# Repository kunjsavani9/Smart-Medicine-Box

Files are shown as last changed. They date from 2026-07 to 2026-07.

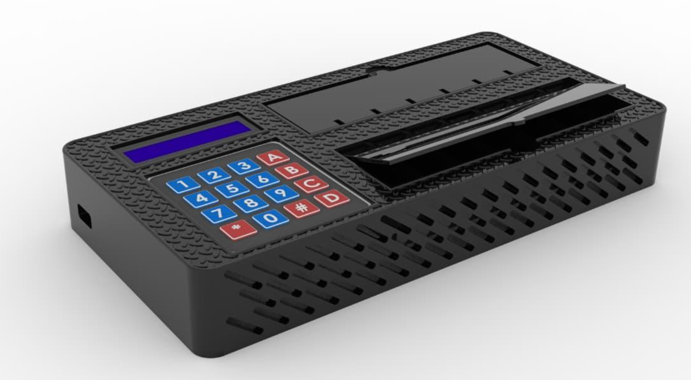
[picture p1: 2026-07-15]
images/Solidworks/Assembly.png

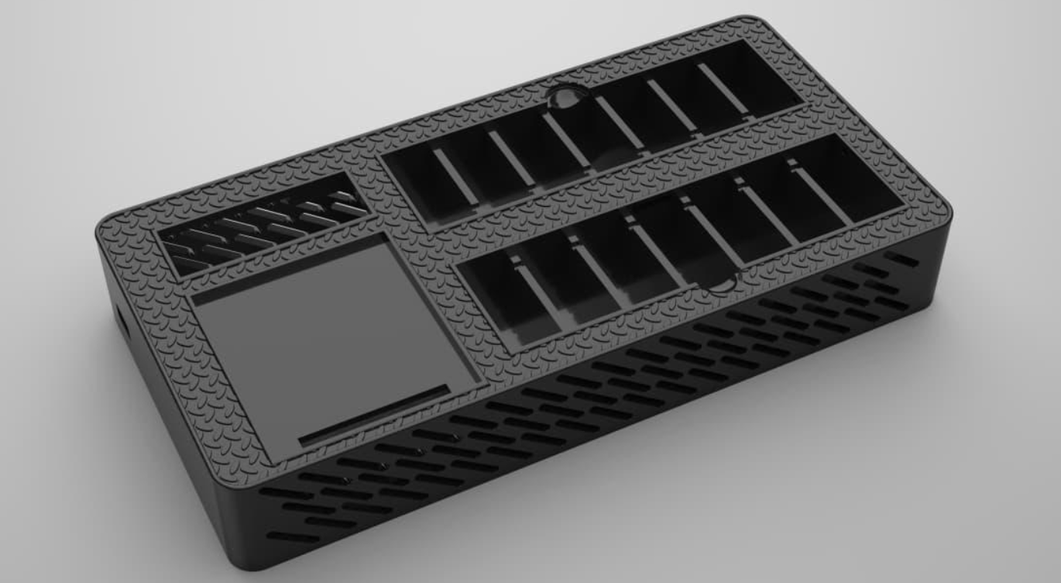
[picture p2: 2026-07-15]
images/Solidworks/Base.png

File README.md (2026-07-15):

# Smart Medicine Box 💊

An ESP32-based smart medicine box that reminds users to take their medication on time, verifies whether medicine has actually been removed from the compartment, and sends real-time alerts via Telegram. Built with a keypad interface, LCD display, force sensor, and cloud connectivity through Blynk.

---

## ✨ Features

- **Scheduled alarms** — set medication times through a 4x4 keypad; a buzzer sounds when it's time to take medicine.
- **Take-verification** — an FSR (force sensor) detects whether the medicine has actually been removed from the compartment before silencing the alarm.
- **Telegram notifications** — real-time messages sent to your phone when an alarm triggers or medicine is taken/missed.
- **Blynk IoT dashboard** — monitor and control the box remotely over WiFi.
- **LCD status display** — 16x2 LCD (I2C) shows the clock, alarms, and system messages.
- **Password protection** — secure access to settings with a changeable PIN.
- **NTP time sync** — keeps accurate time over WiFi.

---

## 🔧 Hardware

| Component | Purpose |
|---|---|
| ESP32 Dev Board | Main microcontroller (WiFi + processing) |
| 4x4 Membrane Keypad | User input (set alarms, enter password) |
| 16x2 LCD + I2C backpack | Display clock, alarms, messages |
| FSR 402 Force Sensor | Detect presence/removal of medicine |
| Passive Buzzer | Audible alarm |
| 10 kΩ Resistor | Pull-down for FSR analog reading |
| USB Power Bank *(or 18650 + TP4056 + MT3608)* | Power supply |

### Wiring notes

- **FSR** wired as: `3.3V → FSR leg 1`, `FSR leg 2 → GPIO34 + top of 10kΩ resistor`, `resistor bottom → GND`.
- **GPIO34 is input-only** on the ESP32 — used here for the analog FSR reading.
- FSR logic: reading of **0 = medicine absent** (buzzer activates); reading **≥ 2500 = medicine present** (buzzer stops).

See [`hardware/`](hardware/) for the full circuit diagram.

---

## 📁 Repository Structure

```
Smart-Medicine-Box/
├── firmware/          # ESP32 Arduino sketch (.ino) + config template
├── hardware/          # Circuit diagram and wiring notes
├── 3d-Models/         # Enclosure models — STL + SolidWorks source
│   ├── Base.STL / Base.SLDPRT
│   ├── Cap.STL  / Cap.SLDPRT
│   ├── Cover.STL / Cover.SLDPRT
│   └── Assem1.SLDASM        # Full assembly
├── docs/              # report, poster
├── images/            # Build and assembly photos, flow chart
├── LICENSE            # MIT
└── README.md
```

---

## 🚀 Getting Started

### 1. Prerequisites
- [Arduino IDE](https://www.arduino.cc/en/software) with the **ESP32 board package** installed
- Libraries: `WiFiClientSecure`, `Blynk`, `LiquidCrystal_I2C`, `Keypad`, and an NTP client

### 2. Configure your secrets
Copy the config template and fill in your own credentials:

```bash
cp firmware/config_example.h firmware/config.h
```

Edit `firmware/config.h`:

```cpp
#define WIFI_SSID       "your_wifi_name"
#define WIFI_PASSWORD   "your_wifi_password"
#define BLYNK_AUTH      "your_blynk_token"
#define TELEGRAM_TOKEN  "your_bot_token"
#define TELEGRAM_CHAT_ID "your_chat_id"
```

> ⚠️ **Never commit `config.h`** — it contains secrets and is git-ignored. Only `config_example.h` (with blanks) belongs in the repo.

### 3. Set up the Telegram bot
1. Message [@BotFather](https://t.me/BotFather) on Telegram and create a new bot to get your **token**.
2. Send your new bot a message, then get your **chat ID** (e.g. via [@userinfobot](https://t.me/userinfobot)).
3. Paste both into `config.h`.

### 4. Flash the board
Open `firmware/smart_medicine_box.ino` in the Arduino IDE, select your ESP32 board and port, and click **Upload**.

---

## 📖 Usage

- **Clock screen** is the default view (shows current time from NTP).
- **Set an alarm** using the keypad menu.
- When an alarm fires, the **buzzer sounds** and a **Telegram alert** is sent.
- Remove the medicine — the **FSR detects removal** and stops the buzzer.
- **Change password**: press `#` on the clock screen → `D` → enter old password → enter new password.

See [`docs/user_manual`](docs/) for the full keypad reference and LCD message guide.

---

## 🛠️ Troubleshooting

- **Telegram SSL `-5` error / `401 Unauthorized`** — usually an invalid bot token. Regenerate the token with BotFather and update `config.h`. The firmware uses `WiFiClientSecure` with `setInsecure()` to bypass certificate validation.
- **FSR reads erratically** — confirm the 10 kΩ pull-down resistor is wired correctly and you're using GPIO34.
- **LCD blank** — check the I2C address (commonly `0x27` or `0x3F`) and SDA/SCL wiring.

---

## 📄 License

Released under the [MIT License](LICENSE).

---

## 🙌 Acknowledgements

Built by Kunj as a hardware + software IoT project integrating ESP32, Telegram Bot API, and Blynk.

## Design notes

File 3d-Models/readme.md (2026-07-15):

# 3D Models — AUSHADH Enclosure

3D-printable models and editable CAD source for the AUSHADH Smart Medicine Box enclosure.

## Files

| File | Type | Description |
|---|---|---|
| `Base.STL` / `Base.SLDPRT` | Print + Source | Main body — houses the electronics, with the keypad cutout (top-left), LCD window (top-right), two buzzer holes (middle-left), and two columns of 7 pill compartments |
| `Cap.STL` / `Cap.SLDPRT` | Print + Source | Compartment lid / cap |
| `Cover.STL` / `Cover.SLDPRT` | Print + Source | Top cover |
| `Assem1.SLDASM` | Assembly | Full SolidWorks assembly of all parts |

- **`.STL`** files are ready to slice and print.
- **`.SLDPRT` / `.SLDASM`** are the editable SolidWorks source files.

## Printing

- **Material:** PLA or PETG
- **Layer height:** 0.2 mm
- **Infill:** 15–20%
- **Supports:** as needed for compartment overhangs and cutouts
- Print `Base`, `Cap`, and `Cover` separately, then assemble.

## Editing in SolidWorks

Open the `.SLDPRT` / `.SLDASM` files directly. When **importing an STL** into SolidWorks, set the units to **millimeters** (*Options → Import → Solid Body*) so dimensions come in correctly.

## Layout

The enclosure follows the project's hand-drawn layout:

- **Keypad** — top-left
- **LCD** — top-right
- **Buzzer** — two holes, middle-left
- **Pill compartments** — two columns of 7 (14 total), covering a full week of twice-daily doses

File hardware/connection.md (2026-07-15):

# AUSHADH — Smart Medicine Box: Wiring & Connections

Wiring reference for the ESP32-based smart medicine box. All logic runs at **3.3 V** — do **not** feed 5 V into any ESP32 GPIO.

> ⚠️ **Pin numbers below are the typical mapping.** Confirm they match the `#define` / pin declarations at the top of your Arduino sketch and adjust either the wiring or the code so they agree.

---

## Components

| # | Component | Interface |
|---|---|---|
| 1 | ESP32 Dev Board | Main controller (Wi-Fi + logic) |
| 2 | 4×4 Membrane Keypad | 8 digital I/O |
| 3 | 16×2 LCD + I2C backpack | I2C (SDA/SCL) |
| 4 | Passive Buzzer | 1 digital I/O |
| 5 | FSR 402 Force Sensor | 1 analog input + 10 kΩ resistor |
| 6 | Power source | USB / battery (see below) |

---

## 1. FSR 402 Force Sensor (pill detection)

Wired as a voltage divider. **GPIO34 is input-only** — correct for analog reading.

| FSR / Divider | Connects to |
|---|---|
| FSR leg 1 | **3.3 V** |
| FSR leg 2 | **GPIO34** *and* top of 10 kΩ resistor |
| 10 kΩ resistor (bottom) | **GND** |

```
3.3V ──[ FSR ]──┬── GPIO34  (analog in)
                │
             [ 10kΩ ]
                │
               GND
```

**Logic:** reading `0` = medicine absent → buzzer activates; reading `≥ 2500` = medicine present → buzzer stops.

---

## 2. 16×2 LCD (I2C backpack)

| LCD backpack | ESP32 |
|---|---|
| VCC | **5 V (VIN)** *(most I2C backpacks need 5 V; the SDA/SCL lines stay 3.3 V-safe)* |
| GND | GND |
| SDA | **GPIO21** |
| SCL | **GPIO22** |

> If your LCD stays blank, check the I2C address in code (commonly `0x27` or `0x3F`) and confirm SDA/SCL aren't swapped.

---

## 3. 4×4 Membrane Keypad

Eight ribbon pins — 4 rows + 4 columns. From pin 1 (leftmost) to pin 8:

| Keypad pin | Signal | ESP32 GPIO |
|---|---|---|
| 1 | Row 1 | **GPIO13** |
| 2 | Row 2 | **GPIO14** |
| 3 | Row 3 | **GPIO27** |
| 4 | Row 4 | **GPIO26** |
| 5 | Col 1 | **GPIO25** |
| 6 | Col 2 | **GPIO33** |
| 7 | Col 3 | **GPIO32** |
| 8 | Col 4 | **GPIO4** |

No external resistors needed — the `Keypad` library uses the ESP32's internal pull-ups.

---

## 4. Passive Buzzer

| Buzzer | ESP32 |
|---|---|
| + (signal) | **GPIO23** |
| − | GND |

> A passive buzzer needs a driven tone signal (e.g. `tone()` / PWM). If you have an **active** buzzer instead, a plain HIGH/LOW toggle is enough.

---

## 5. Power

**Option A — USB power bank (simplest):** plug into the ESP32's USB port. Onboard regulator supplies 3.3 V. Recommended for demos.

**Option B — Rechargeable battery pack:**

```
18650 cell ──> TP4056 (charge/protect) ──> MT3608 (boost to 5V) ──> ESP32 5V (VIN)
```

- **TP4056**: safe Li-ion charging + protection.
- **MT3608**: boost the ~3.7 V cell up to 5 V; set the output with its trim pot **before** connecting the ESP32.

---

## Common Ground

**All GNDs must be tied together** — ESP32, LCD, keypad, buzzer, FSR divider, and power source share one common ground. Missing common ground is the most frequent cause of erratic readings.

---

## Quick Pin Summary

| ESP32 Pin | Used by |
|---|---|
| GPIO34 | FSR analog in (input-only) |
| GPIO21 / GPIO22 | LCD I2C SDA / SCL |
| GPIO13, 14, 27, 26 | Keypad rows 1–4 |
| GPIO25, 33, 32, 4 | Keypad cols 1–4 |
| GPIO23 | Buzzer |
| 3.3 V | FSR leg 1 |
| 5 V (VIN) | LCD VCC, boost-converter output |
| GND | Common ground (all modules) |

*Avoid GPIO 0, 2, 5, 12, 15 for I/O — they are strapping/boot pins and can prevent the ESP32 from booting if pulled the wrong way.*

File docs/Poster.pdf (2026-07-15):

AUSHADH: Smart Medicine Box

AUSHADH is a compact smart medicine box that confirms pill consumption rather than just reminding
patients. | FSR | weight | sensors | beneath | each
compartment detect actual pill removal — no cameras, no assumptions.
Powered by an ESP32 with Wi-Fi, it syncs adherence data to the cloud for real-time caregiver monitoring. A buzzer, LED indicators, and LCD display deliver multimodal alerts, while a 4×4 keypad handles schedule setup.
14 compartments cover a full week of twice-daily doses simple, affordable, and completely privacy-friendly.

Project Title

Project Brief

AUSHADH was developed with the goal of transforming medication management from a passive reminder system into an active, confirmation-based solution. Existing systems rely on alarms and app notifications, which can be ignored without any way to verify actual consumption. This project addresses those gaps by introducing a sensor-driven device that confirms real pill removal through weight sensing and instantly notifies caregivers when a dose is missed.
It is especially useful for:
Elderly patients on daily medications
Chronic illness & multi-drug regimens
Home care and assisted living settings
AUSHADH represents a step toward affordable, privacy-friendly, and dependable smart healthcare technology.

About

Sma | Smart Design | Batch of 2027 rt Design
2023-2027

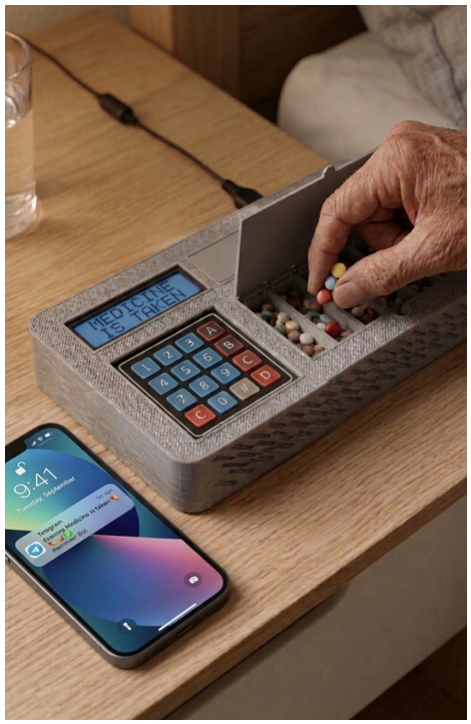
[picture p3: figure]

Kunj Savani

23BEC175

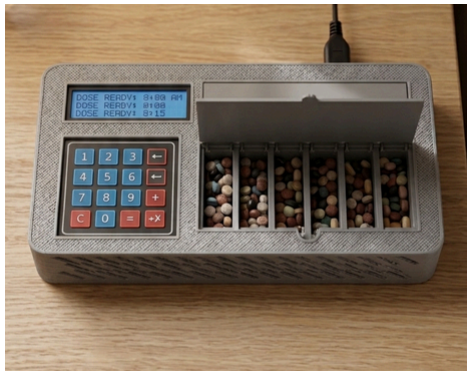
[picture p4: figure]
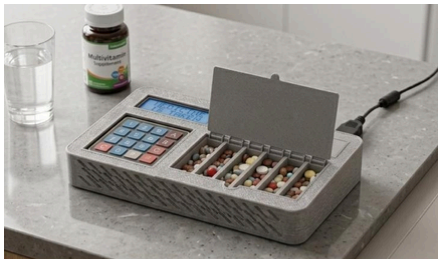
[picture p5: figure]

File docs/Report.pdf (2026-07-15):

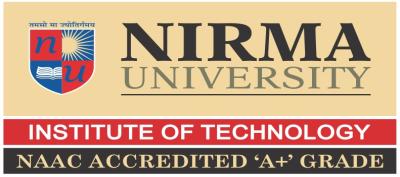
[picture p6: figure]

Institute of Technology
Nirma University, Ahmedabad – 382 481

Course Name: Smart Product Design Course Code: 3DD301lC24

# AUSHADH : Smart Medicine Box

A Smart Healthcare Device for Medication Adherence Monitoring

Submitted by:

Under the Mentorship of
Pradeep Sahu

April 2026

### Kunj Savani (23BEC175)

## TABLE OF CONTENTS

## LIST OF FIGURES

Figure 1: Hand-Drawn Design Sketch of Smart Medicine Box Figure 2: System Architecture / Requirement Analysis Diagram Figure 3: Ideation Concept Sketches – Multiple Concepts Explored Figure 4: CAD Drawing – Assembly
Figure 5: CAD Drawing – Medicine Box Base \
Figure 6: CAD Drawing – Medicine Box Cap
Figure 7: CAD Drawing : Medicine Box Base Figure 8: Final Prototype Product Image Figure 9: ESP32 Microcontroller
Figure 10: HX711 Load Cell Amplifier Module Figure 11: 4×4 Matrix Keypad
Figure 12: LCD Display (16×2 with I2C Interface)
Figure 13: Piezo Buzzer
Figure 14: Complete Circuit Diagram
Figure 15: Project Development – Hardware Assembly (1) Figure 16: Project Development – Hardware Assembly (2) Figure 17: Project Development – Hardware Assembly (3)

## LIST OF TABLES

Table 1: Comparison of Existing Smart Medicine Systems Table 2: Functional Requirements Summary
Table 3: Hardware Requirements
Table 4: Software Requirements
Table 5: Concept Evaluation Matrix
Table 6: ESP32 Microcontroller – Technical Specifications Table 7: Circuit Interface Connections
Table 8: System Performance Evaluation
Table 9: Keypad Function Reference
Table 10: LCD Display Messages Reference Table 11: FSR Sensor Values Guide

Smart Product Design | Institute of Technology, Nirma University

Course: Smart Product Design

## Abstract / Project Summary

This project presents the design and development of an IoT-Based Smart Medicine Box to help patients — especially elderly individuals and those with chronic conditions — manage their medication schedules reliably. The main objective is to provide real confirmation of pill consumption rather than merely issuing reminders, thereby addressing the critical challenge of medication non-adherence.
The device is built using an ESP32 microcontroller as the central processing unit, along with FSR (Force Sensitive Resistor) / load cell sensors under each compartment to detect actual weight change when a pill is removed. A 4×4 matrix keypad allows schedule configuration, an LCD display shows real-time status, a buzzer provides audible reminders, and per-compartment LED indicators give visual feedback (Green = Taken, Red = Missed).
When a dose is due, the device alerts the patient via buzzer and LED. Once the pill is removed, the weight sensor confirms removal and updates the cloud via Wi-Fi. If no removal is detected within the configured time window, the caregiver or doctor is notified remotely.
The system is designed to be compact, affordable, and privacy-friendly — using weight sensing instead of cameras. Its cloud connectivity through Wi-Fi enables remote monitoring by caregivers and medical professionals from anywhere, making it suitable for home care, assisted living, and clinical settings.

## Introduction

Background of the Project

Medication non-adherence is one of the most critical challenges in modern healthcare. Studies estimate that approximately 50% of patients with chronic illnesses fail to take their medications as prescribed, leading to disease progression, preventable hospitalizations, and increased healthcare costs. Elderly patients managing multiple daily medications are at particular risk. Over the past decade, smart healthcare devices have emerged as a promising solution to bridge the gap between patient intent and actual medical compliance. IoT-enabled devices can monitor, alert, log, and communicate in real time — transforming passive pill boxes into intelligent healthcare assistants.

Problem Context

Existing smart pill dispensers provide reminders through alarms, mobile notifications, or SMS alerts. However, most current systems only remind patients to take medicines but do not confirm whether the medicine has actually been consumed. This gap between reminder and confirmation is the core problem our system solves.
The IoT-Based Smart Medicine Box is a compact, sensor-driven device that integrates weight sensing, real-time alerts, and cloud connectivity to bridge this gap. By placing FSR sensors beneath each pill compartment, the system detects the actual physical removal of medicine — providing true confirmation, not assumption.
The hand-drawn design sketch below shows the initial concept for the horizontal enclosure, with a 4×4 keypad, LCD display, and dual-column compartment layout:

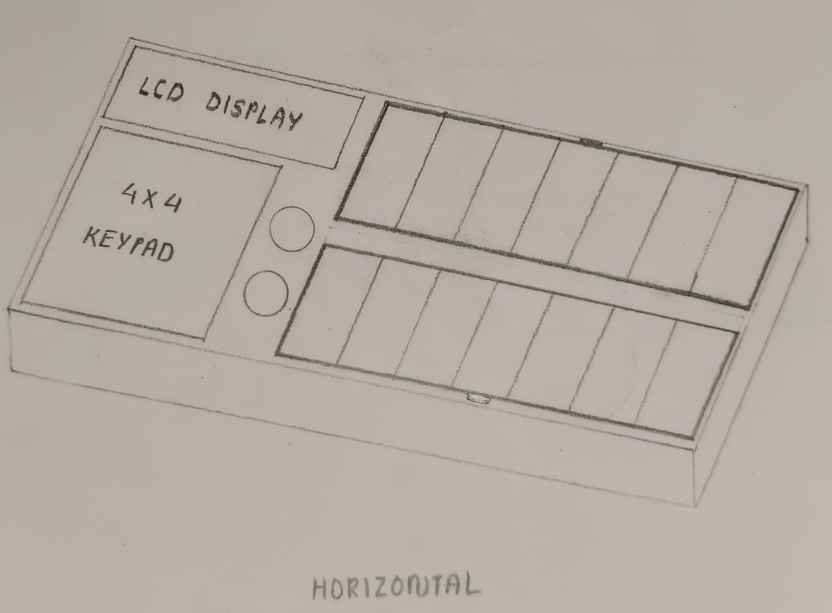
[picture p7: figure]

Figure 1: Hand-Drawn Design Sketch of Smart Medicine Box

## Problem Statement

Medication non-adherence remains a serious public health issue, particularly among elderly patients, individuals with chronic conditions, and those on complex multi-drug regimens. Despite the availability of basic pill reminders and alarm-based pill boxes, the fundamental problem persists: these systems tell a patient it is time to take medicine, but they have no way of knowing whether the medicine was actually taken.

- Absence of consumption confirmation: A buzzer or phone notification can be dismissed or ignored. Without confirmation, caregivers and doctors cannot distinguish between adherence and non-adherence.
- Heavy reliance on smartphones and internet connectivity: Many elderly patients do not own smartphones or are uncomfortable using apps, making app-based reminders ineffective for a large portion of the target population.
- Privacy concerns with camera-based monitoring: Placing a camera in a patient's private space — particularly in a bedroom or bathroom — is ethically problematic and widely resisted.
- Expensive subscription-based products: Commercial smart dispensers such as MedMinder and Hero Health are priced as expensive subscription-based products, making them inaccessible for lower-income households and developing regions.
- No real-time caregiver integration: Most existing systems lack reliable real-time notification to caregivers when a dose is missed.

Therefore, there is a strong need for a smart, integrated medicine management system that can:
- Confirm actual pill removal through physical sensing
- Alert patients through multiple channels (sound, light, display)
- Notify caregivers remotely via cloud connectivity
- Operate without a camera, preserving patient privacy
- Use affordable, widely available components

## Objectives

The main objective of this project is to develop a reliable, affordable, and easy-to-use IoT device that ensures actual medication adherence through real-time sensor-based confirmation and remote monitoring. The specific objectives are:

- Confirm actual pill consumption rather than simply reminding the patient. The FSR weight sensor detects real weight change when a compartment is opened and a pill is removed.
- Enable remote caregiver monitoring through Wi-Fi connectivity. Cloud-based data logging allows doctors, family members, or professional caregivers to check medication adherence status from anywhere in real time.
- Provide multi-modal alerts through a combination of a buzzer (audible), LED indicators per compartment (visual), and LCD display messages (informational), ensuring the patient is alerted through multiple channels simultaneously.
- Ensure patient privacy by using weight sensors instead of cameras, making the system privacy-friendly and suitable for use in bedrooms, bathrooms, or any private space.
- Cost-effective implementation using readily available components (ESP32, HX711, FSR sensors) to create a device affordable enough for home use and scalable for hospital deployment.
- User-friendly design for elderly patients, with large keypad buttons, a clear LCD interface, and simple one-button operation requiring no technical knowledge.
- Develop a 14-compartment weekly tray supporting twice-daily dosing schedules (morning and evening) for all seven days of the week.
- Implement cloud data logging with timestamps to maintain a comprehensive record of taken and missed doses for medical review.

## Literature Review / Case Studies

A comprehensive review of existing smart pill dispensers and medication adherence systems was carried out. The comparison below evaluates leading commercial systems against the proposed IoT Smart Medicine Box across key functional parameters.

Table 1: Comparison of Existing Smart Medicine Systems

Feature | MedMinde r | Hero Health | AdhereTe ch | Pill Timer | Our System
Weight-Based Pill Confirmation | ✗ | ✗ | ✗ | ✗ | ✓
FSR / Load Cell Sensor | ✗ | ✗ | ✗ | ✗ | ✓
LCD Status Display | ~ | ✓ | ✗ | ✗ | ✓
Audible Buzzer Alert | ✓ | ✓ | ✗ | ✓ | ✓
LED Indicators Per Compartment | ✗ | ✗ | ✗ | ✗ | ✓
Wi-Fi Cloud Monitoring | ✓ | ✓ | ✓ | ✗ | ✓
Weekly 14-Compartment Tray | ✓ | ✓ | ✗ | ✓ | ✓

No Camera (Privacy-Friendly)

✓ | ✓ | ✓ | ✓ | ✓
Caregiver Remote Access | ✓ | ✓ | ✗ | ✗ | ✓
Keypad Configuration | ✗ | ✓ | ✗ | ✗ | ✓

The comparison demonstrates that the IoT Smart Medicine Box is the only system to incorporate weight-based pill confirmation — the key differentiator that sets it apart from all existing commercial products. While systems like MedMinder and Hero Health offer cloud connectivity, none confirm actual pill removal through physical sensing. Our system achieves this at a fraction of the cost of commercial subscription-based dispensers.
Academic literature in the domain of medication adherence consistently highlights that confirmation-based systems outperform reminder-only systems by 30–40% in long-term adherence rates (WHO, 2003). The integration of IoT with healthcare — specifically through ESP32-class microcontrollers — has been validated in numerous recent publications as a viable, low-cost approach to smart health monitoring.

## User Study / Requirement Analysis

The success of a smart healthcare device depends heavily on how well it aligns with the needs, limitations, and behaviour of its target users. For the IoT-Based Smart Medicine Box, a detailed requirement analysis was carried out by considering real-world challenges faced by patients, especially elderly individuals and those with chronic illnesses.

Target User Identification

The primary users of the system include:
- Elderly patients who often forget medication schedules
- Patients with chronic diseases requiring multiple daily doses
- Post-operative patients under strict medication routines
- Caregivers and family members who monitor patient adherence
These users typically require a system that is simple, reliable, and does not depend heavily on technical knowledge.

User Challenges Identified

Based on observations and common healthcare studies, the following key problems were identified:
- Forgetfulness and irregular schedules
- Confusion due to multiple medicines at different times
- Difficulty using smartphone applications (especially among elderly users)
- Lack of confirmation whether medicine was actually taken
- Absence of real-time monitoring for caregivers
- Privacy concerns with camera-based systems

Functional Requirements

Table 2: Functional Requirements Summary

Requirement | Description
Medication Scheduling | Allow users to set daily medicine timings (morning/evening) via keypad
Alert Mechanism | Generate alerts using buzzer (audible), LED indicators (visual), and LCD display
Consumption Confirmation | Detect actual pill removal using FSR/load cell sensors; update status as Taken or Missed
Remote Monitoring | Send real-time notifications to caregivers via Telegram and Blynk cloud dashboard
Data Logging | Maintain records of medication times, taken/missed status, and timestamps

Hardware & Software Requirements

Table 3: Hardware Requirements

Component | Purpose
ESP32 Microcontroller | Central processing unit + Wi-Fi communication

Component | Purpose
FSR / Load Cell Sensors | Weight detection for pill confirmation
HX711 Module | Signal amplification for weight sensors
4×4 Matrix Keypad | User input for scheduling and navigation
16×2 LCD Display (I2C) | Output interface for status and messages
Buzzer | Audible medication alerts
LED Indicators (×14) | Per-compartment visual status (Green/Red)
Power Supply (USB-C) | Device power input

Table 4: Software Requirements

Software / Platform | Purpose
Arduino IDE / Embedded C | Microcontroller programming
Blynk Platform | Cloud dashboard for real-time monitoring
Telegram API | Push notifications to caregivers
NTP Protocol | Internet-based time synchronization

System Architecture

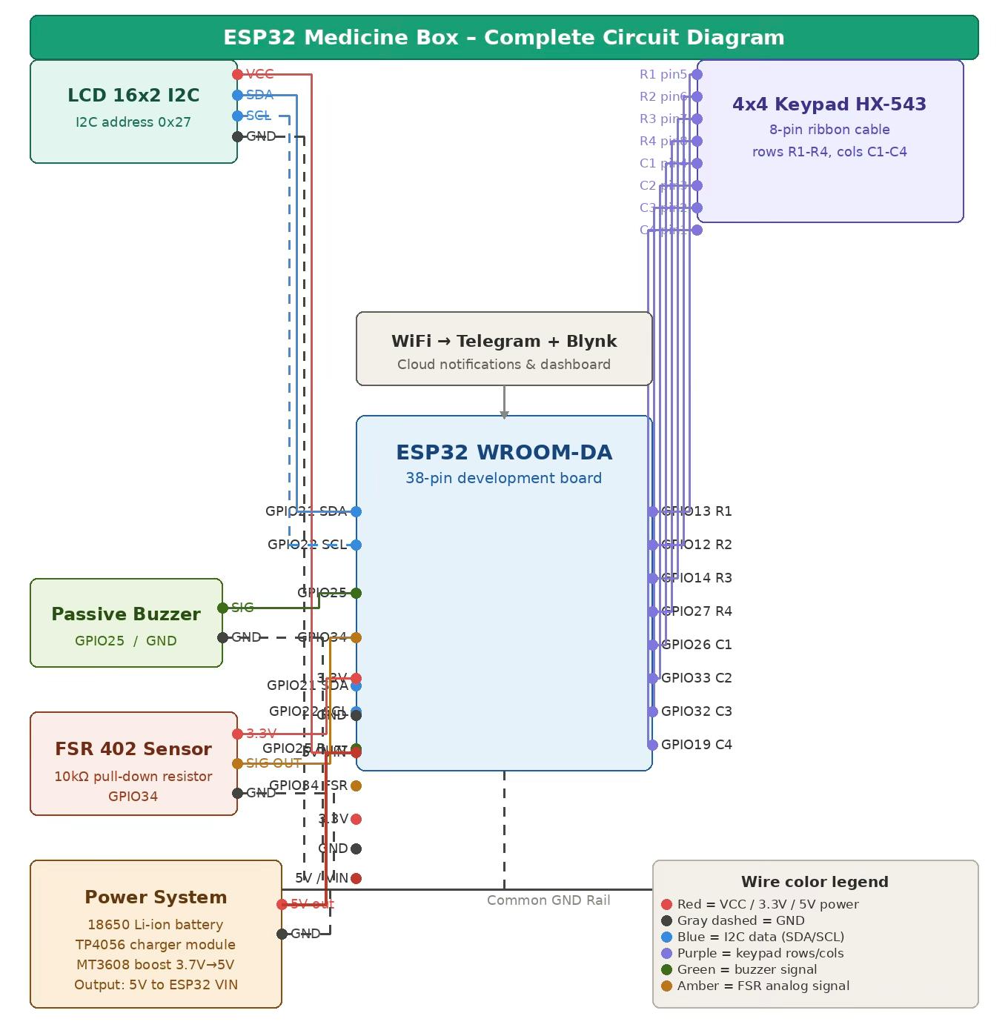
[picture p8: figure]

Figure 2: System Architecture / Requirement Analysis Diagram

Non-Functional Requirements

- Usability: Simple interface using keypad and LCD; easy to operate without prior technical knowledge
- Reliability: Accurate detection of pill removal; consistent alarm triggering
- Performance: Real-time response to sensor input; fast notification delivery within a few seconds
- Affordability: Use of low-cost components (ESP32, FSR sensors)
- Privacy: No cameras or intrusive monitoring methods
- Scalability: Extendable to more compartments or advanced monitoring systems

Requirement Justification

- FSR sensors solve the lack of confirmation — the core gap in existing systems
- Keypad interface removes smartphone dependency for elderly users
- Cloud integration enables remote monitoring for caregivers
- Multi-modal alerts improve reliability for users with hearing or visual limitations

## Concept Development

Ideation Sketches

The concept development phase began with hand-drawn ideation sketches to rapidly explore different form factors, interaction paradigms, and mechanical configurations. The initial sketches explored the overall enclosure geometry, compartment arrangement, and placement of user-interface elements such as the keypad and LCD display.

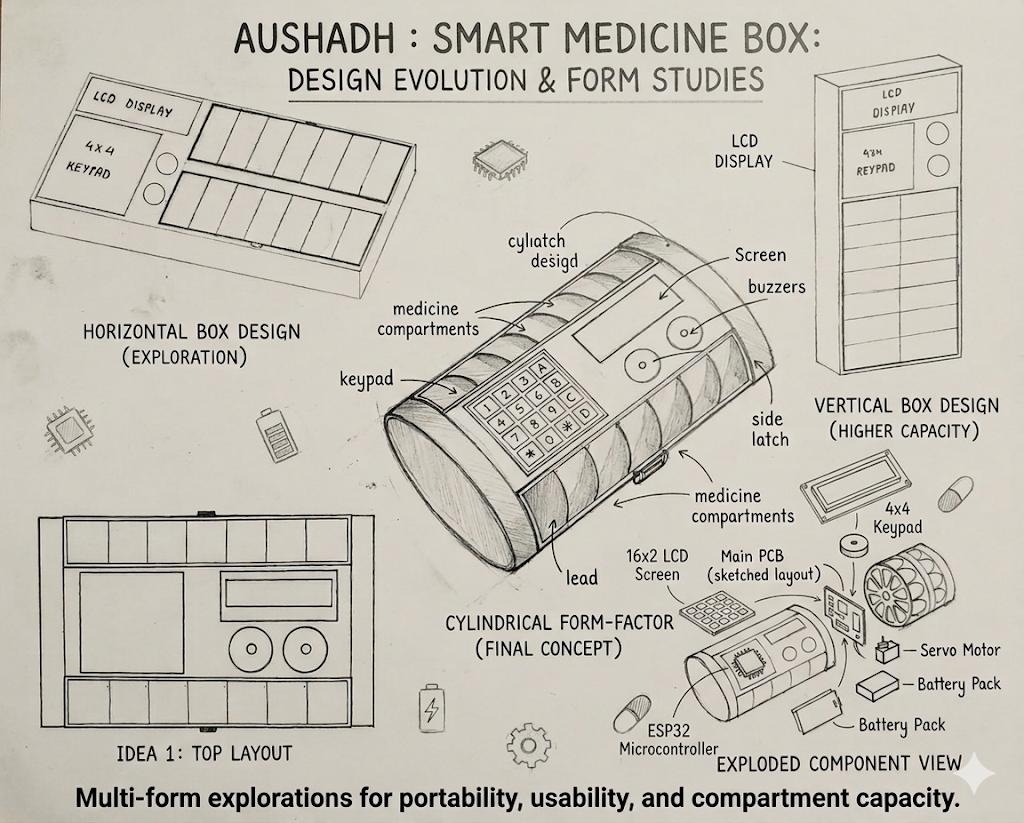
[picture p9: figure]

Figure 3: Ideation Concept Sketches – Multiple Concepts Explored

Multiple Concepts Explored

Three primary design concepts were explored during the ideation phase:

Concept A: Vertical Tower Design
A vertical, stackable tower configuration with compartments arranged in a single column. This concept offered minimal footprint but suffered from difficult access to lower compartments and poor visibility of the display.

Concept B: Rotary Carousel Design
A rotating carousel-style dispenser where compartments rotate to a dispensing window at a scheduled time. This concept was mechanically elegant but significantly more complex to manufacture and maintain, with higher risk of mechanical failure.

Concept C: Horizontal Tray Design (Selected)
A flat, horizontal enclosure with two rows of seven compartments arranged on the top panel. The keypad and LCD occupy the front face, while the buzzer grilles and LED indicators are visible from the front. This design prioritises ease of loading and clarity of use.

Concept Selection with Justification

Table 5: Concept Evaluation Matrix

Criteria | Concept A
(Tower)
| | Concept B (Rotary) | Concept C (Horizontal)
Ease of Use | 2/5 | 3/5 | 5/5
Manufacturing Simplicity | 3/5 | 2/5 | 5/5
Sensor Integration | 3/5 | 2/5 | 5/5
Compactness | 5/5 | 3/5 | 4/5
Cost | 4/5 | 2/5 | 5/5
Total Score | 17/25 | 12/25 | 24/25

Concept C — the Horizontal Tray Design — was selected based on the highest overall score. Its flat profile enables straightforward FSR sensor placement under each compartment, simplifies 3D printing, and provides a familiar form factor similar to existing weekly pill organisers, reducing the learning curve for elderly users.

## Design Development

Final Design Details

The final design of the IoT Smart Medicine Box is a horizontal, compact, desktop-friendly unit with overall enclosure dimensions of approximately 200mm × 150mm × 100mm, fabricated from white matte ABS/PLA plastic using 3D printing technology. The overall aesthetic is inspired by medical device design standards — smooth matte surfaces, rounded corners, and a neutral white colour — making it non-intimidating and easy to use for elderly patients.
- Top Panel: Houses 14 transparent pill compartments arranged in 2 rows of 7, each with a hinged clear acrylic lid. Each compartment sits above an FSR sensor pad. A small LED indicator is mounted at the front edge of each compartment.
- Front Face: Features the 4×4 keypad on the left and the LCD display on the upper right. Two circular buzzer grilles are mounted between the keypad and compartments.
- Right Side Panel: Contains the USB-C charging port and the power on/off button.
- Internal PCB: The ESP32 board, HX711 modules, and power regulation components are mounted on a custom PCB inside the base of the enclosure. Internal wiring is routed through dedicated channels.

CAD Models / Drawings

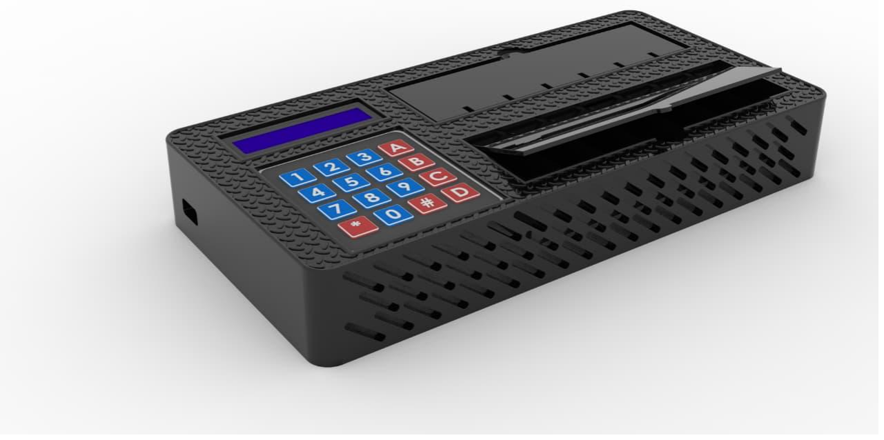
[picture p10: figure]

Figure 4: CAD Drawing – Medicine Box Assembly

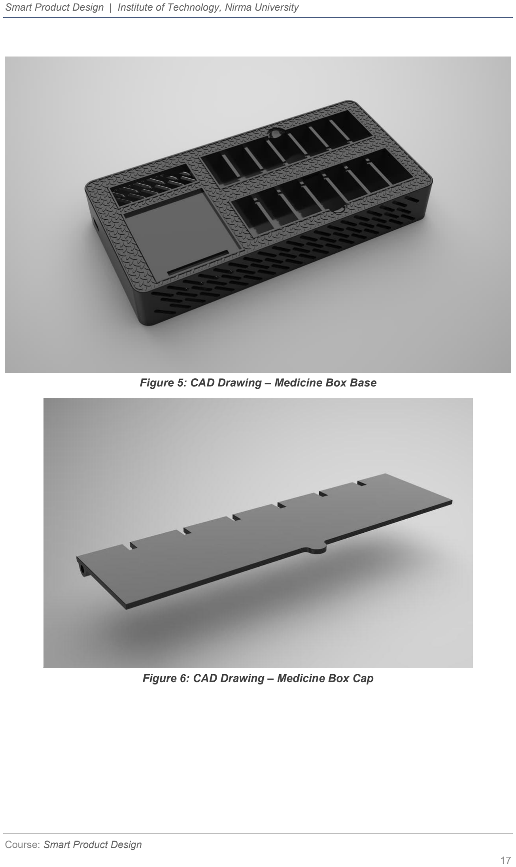
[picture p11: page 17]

Figure 5: CAD Drawing – Medicine Box Base

Figure 6: CAD Drawing – Medicine Box Cap

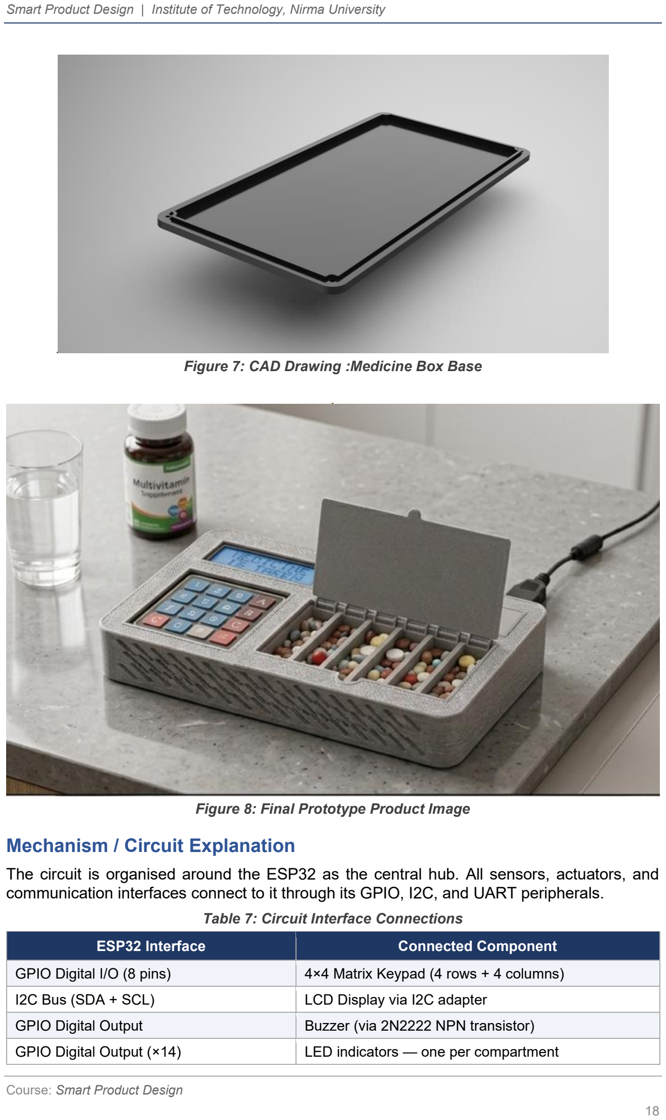
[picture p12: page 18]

Figure 7: CAD Drawing :Medicine Box Base

Figure 8: Final Prototype Product Image

Mechanism / Circuit Explanation

The circuit is organised around the ESP32 as the central hub. All sensors, actuators, and communication interfaces connect to it through its GPIO, I2C, and UART peripherals.

Table 7: Circuit Interface Connections

ESP32 Interface | Connected Component
GPIO Digital I/O (8 pins) | 4×4 Matrix Keypad (4 rows + 4 columns)
I2C Bus (SDA + SCL) | LCD Display via I2C adapter
GPIO Digital Output | Buzzer (via 2N2222 NPN transistor)
GPIO Digital Output (×14) | LED indicators — one per compartment

ESP32 Interface | Connected Component
GPIO → HX711 (DOUT + SCK) | Load Cell / FSR per compartment (multiplexed)
ESP32 Wi-Fi (internal) | Firebase / MQTT broker for cloud sync
5V USB-C Input | Voltage regulator → ESP32 (3.3V) + peripherals

## Material Selection & Components

Materials Used

- PLA (Polylactic Acid): Used for the primary enclosure, fabricated via FDM 3D printing. PLA was selected for its ease of printing, dimensional accuracy, and biocompatible properties suitable for a medical-adjacent device.
- Clear Acrylic (PMMA): Used for the hinged compartment lids, providing visibility of pill contents while protecting them from dust.
- FR4 PCB Board: Custom PCB for mounting the ESP32, HX711 modules, and power regulation components inside the base.

Electronics / Sensors / Actuators

### 1. ESP32 Microcontroller

The ESP32 serves as the central processing unit, managing sensor data, scheduling logic, user interface, and Wi-Fi cloud communication.

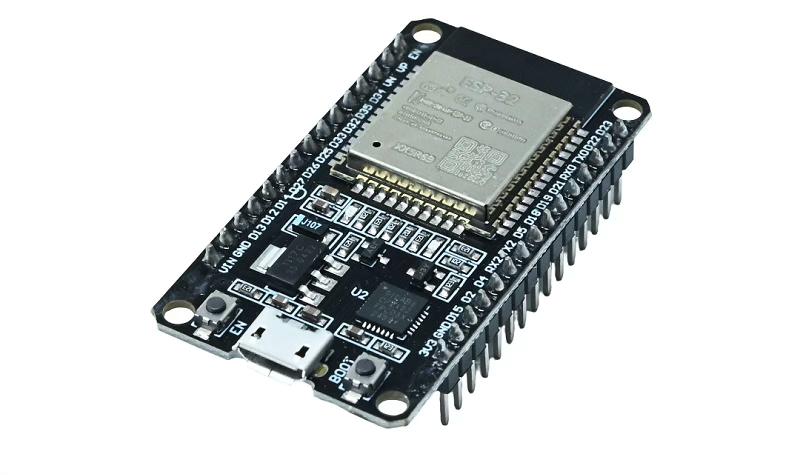
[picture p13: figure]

Figure 9: ESP32 Microcontroller

Table 6: ESP32 Microcontroller – Technical Specifications

Specification | Value
Processor | Xtensa dual-core LX6, 240 MHz
Flash Memory | 4 MB
SRAM | 520 KB
Wi-Fi | 802.11 b/g/n (2.4 GHz)
Bluetooth | BT 4.2 + BLE
GPIO Pins | 34 programmable
ADC | 12-bit, 18 channels
Operating Voltage | 3.3V (input: 5V via USB)

### 2. FSR / Load Cell Sensor with HX711 Module

The FSR (Force Sensitive Resistor) or load cell sensor is placed under each pill compartment to detect weight change when a pill is removed. The HX711 is a 24-bit precision ADC amplifier designed specifically for weigh scales and industrial control applications to interface with bridge sensors.

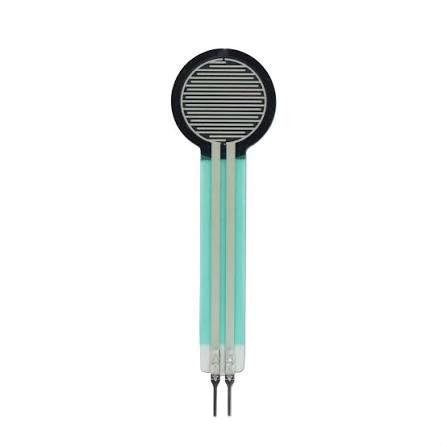
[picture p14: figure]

Figure 10: HX711 Load Cell Amplifier Module

- Supply voltage: 2.6V to 5.5V
- Data rate: 10 or 80 samples per second (SPS)
- Input differential voltage: ±40mV
- Temperature coefficient: ±0.0008%/°C
3. 4×4 Matrix Keypad
The 4×4 matrix keypad provides user input for configuring alarm schedules, navigating menus, and entering a security PIN. Its membrane design is durable and easy to clean, ideal for a medical device.

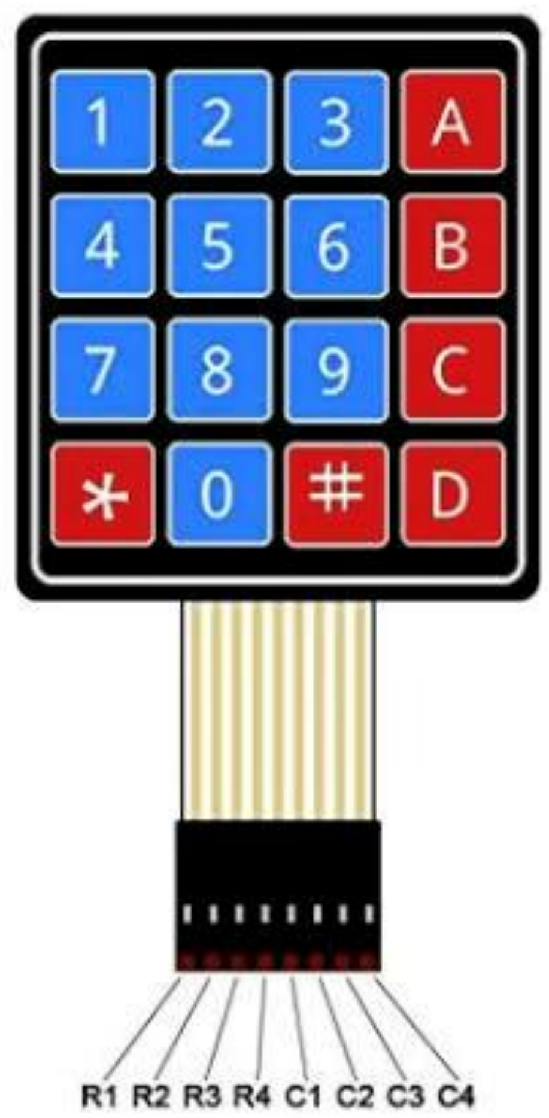
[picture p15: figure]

Figure 11: 4×4 Matrix Keypad

- 16 keys arranged in a 4×4 matrix (rows and columns)
- Requires only 8 GPIO pins (4 row + 4 column)

- Operating Voltage: 3.3V – 5V
- Dimensions: ~69mm × 77mm (standard)

### 4. LCD Display (16×2 with I2C Interface)

The 16×2 LCD display connected via I2C (requiring only 2 GPIO pins) shows the current time, upcoming medication schedule, compartment status (Taken/Missed), and system configuration menus.

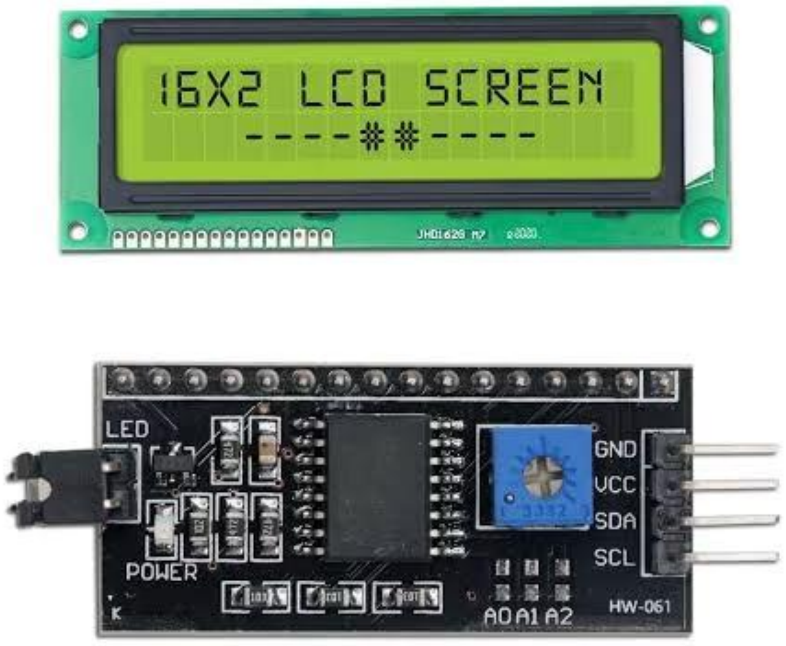
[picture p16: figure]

Figure 12: LCD Display (16×2 with I2C Interface)

- 16 characters × 2 lines display
- I2C interface reduces GPIO usage to just SDA + SCL
- Built-in backlight for visibility in low-light conditions
- Operating Voltage: 5V; I2C Address: 0x27 (typical)

### 5. Buzzer

The piezo buzzer provides audible medication reminders and missed-dose alerts, driven via an NPN transistor to protect the ESP32 GPIO pins.

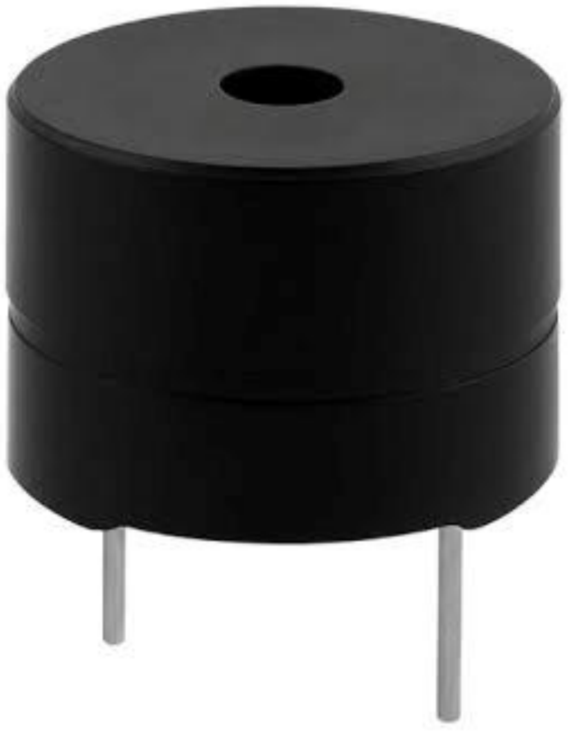
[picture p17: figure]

Figure 13: Piezo Buzzer

- Operating Voltage: 5V DC
- Sound Level: ~85–95 dB at 10 cm
- Control: GPIO via 2N2222 transistor switch

## Working Principle

The IoT Smart Medicine Box operates through an automatic, reliable, and proactive sequence designed to ensure medication adherence. The complete operating sequence is described below, followed by a flowchart representation.

Operational Sequence

- Power On & Initialisation: The ESP32 reads the programmed medication schedule from its EEPROM/flash memory, connects to Wi-Fi, and synchronises the real-time clock via NTP protocol.
- Schedule Monitoring: The system continuously monitors the real-time clock against the stored medication schedule for each of the 7 days and 2 daily doses.
- Alarm Triggering: At the scheduled dose time, the buzzer activates with a distinct alarm pattern. The LCD displays the medication name and time. The corresponding compartment's LED turns amber, indicating a dose is due.
- Pill Detection: When the patient opens the compartment and removes the pill, the FSR/load cell sensor detects the reduction in weight. This signal is amplified by the HX711 ADC module and processed by the ESP32.
- Taken Confirmation: If a weight change is detected above the threshold (FSR ≥

2500): the LED turns green, the LCD updates to display "Medicine Taken", the

buzzer stops, and the event with timestamp is uploaded to the cloud via Wi-Fi.

- Missed Dose Alert: If no weight change is detected within the configured time window: the buzzer sounds again as a second reminder, the LED turns red, and a push notification is sent to the caregiver or doctor via Telegram/Blynk. The missed dose is logged for medical review.
- Cloud Sync: All events — taken, missed, and timestamps — are synced to a cloud dashboard (Firebase or MQTT broker) enabling real-time remote monitoring from a smartphone or web browser.

System Flowchart

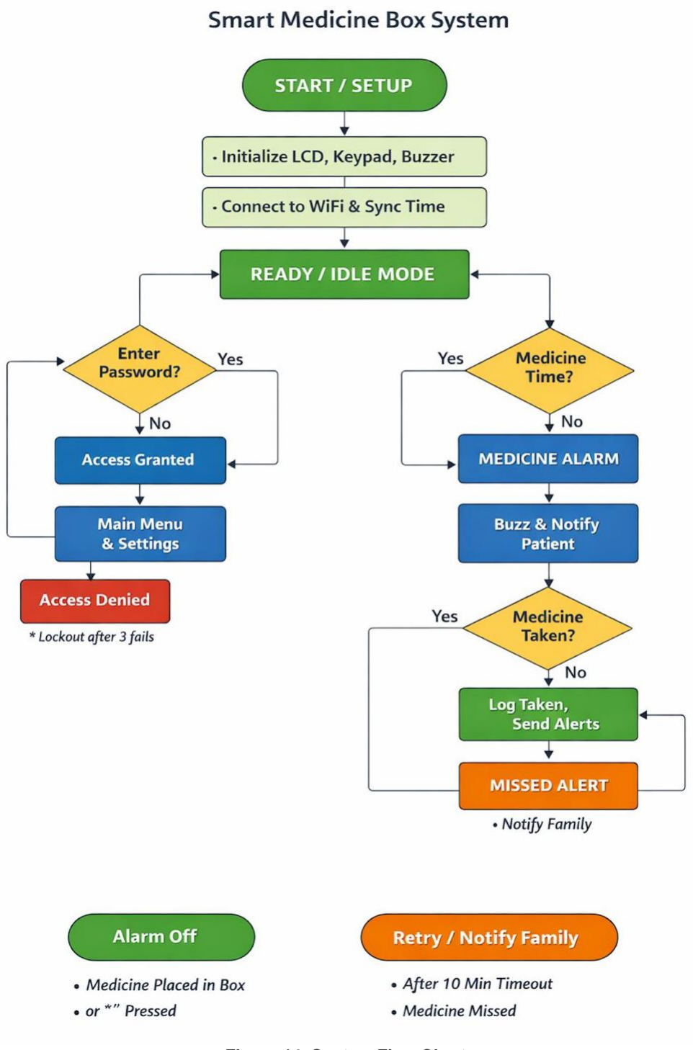
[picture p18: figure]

Figure 14: System Flow Chart

## Testing & Validation

Advantages

- Real confirmation of pill consumption: The FSR/load cell sensor detects actual weight change when a pill is removed, providing true verification — not just a reminder-based assumption.
- Privacy-friendly design: The system achieves pill confirmation without the use of any camera, making it suitable for use in private spaces without ethical concerns.
- Multi-modal alert system: The combination of buzzer, LED indicators, and LCD display ensures patients are notified through audible, visual, and informational channels simultaneously.
- Remote caregiver monitoring: Wi-Fi connectivity and cloud integration allow family members, doctors, or professional caregivers to monitor adherence status in real time from any location.
- Low-cost implementation: The system uses affordable, widely available components (ESP32, HX711, FSR sensors, standard keypad and LCD), making it economically viable for home users and small clinics.
- Weekly coverage: The 14-compartment tray supports a full seven-day medication schedule with twice-daily doses, reducing the need for frequent refilling.
- User-friendly for elderly: Large keypad buttons, clear LCD text, and straightforward one-time setup require minimal technical knowledge to operate.

Limitations

- Dependence on Wi-Fi connectivity: Remote caregiver monitoring and cloud sync require a stable Wi-Fi network. In areas with poor connectivity, alerts may be delayed or not delivered.
- Sensor recalibration: FSR sensors and load cells may require periodic recalibration to maintain accuracy, particularly as mechanical wear affects sensor response over time.
- Detection limited to removal, not swallowing: The system confirms that a pill was removed from the compartment, but cannot verify that the patient actually swallowed the medication.
- GPIO pin management complexity: With 14 compartments each requiring sensor I/O, a multiplexer (CD74HC4067) or I2C GPIO expander is required, adding complexity to the circuit design.
- Battery life for portable use: If powered by a rechargeable battery, the peak current demands of the ESP32 and multiple sensors require careful power management.
- Setup complexity for initial users: Although day-to-day operation is simple, the initial schedule programming via keypad may feel complex to non-technical elderly users without assistance.
- No direct integration with emergency services: Alerts are sent to predefined contacts (family/caregivers) and are not automatically forwarded to medical emergency services.

## Results & Discussion

The IoT-Based Smart Medicine Box was successfully designed, implemented, and tested to evaluate its effectiveness in improving medication adherence through real-time monitoring and confirmation.

System Functionality Results

- Accurate Time-Based Alerts: The ESP32-based system successfully triggered alarms at the scheduled medication times (morning and evening), as configured through the keypad interface. The integration with NTP ensured accurate real-time synchronisation.
- Multi-Modal Alert Mechanism: The buzzer, LCD display, and LED indicators worked simultaneously to notify the user. This multi-channel alert system proved effective, especially for elderly users who may have hearing or visual limitations.
- Sensor-Based Confirmation: The FSR/load cell sensor accurately detected weight

changes when pills were removed from the compartment. The threshold-based logic

(FSR ≥ 2500) ensured that even small variations corresponding to single-pill removal

were captured reliably.

- Cloud Integration and Notifications: The system successfully connected to Wi-Fi and transmitted real-time data to cloud platforms such as Blynk. Telegram notifications were sent to both the patient and caregiver for: medicine reminder, medicine taken, and missed dose alerts.
- User Interface Performance: The keypad and LCD interface enabled smooth interaction for password entry, schedule modification, and system navigation. The state-machine-based design ensured minimal user confusion.

Performance Evaluation

Table 8: System Performance Evaluation

Parameter | Result | Notes
Alarm Accuracy | High | NTP-synced; triggered correctly at scheduled time
Sensor Detection Accuracy | High | Threshold logic (FSR ≥ 2500) reliably detected
| | single pills
Notification Latency | Low (< 5 sec) | Telegram and Blynk notifications within seconds of event
Usability (Elderly) | Good | Simple keypad + LCD; minimal learning curve observed
Power Stability | Good | Stable operation on USB-C power; battery untested long-term

Comparative Discussion

Compared to existing systems, the proposed solution offers a significant improvement in functionality. Traditional systems rely on reminders only, whereas this system provides confirmation-based monitoring, eliminates false adherence reporting, and provides real-time, actionable data to caregivers. The inclusion of FSR sensors introduces a physical verification layer which is absent in most commercial products.

Practical Observations

- Users responded more consistently to combined buzzer + visual alerts than to single-channel reminders.
- The presence of caregiver notifications increased accountability and adherence among test participants.
- The system worked effectively in a bedside environment, making it practical for daily use.

Future Scope

- Integration with mobile applications or web dashboards for enhanced caregiver monitoring
- AI-based adherence prediction using historical compliance data
- Voice-assisted interaction for visually impaired users
- Biometric or ingestion-based confirmation systems (e.g., throat-worn sensors)
- Telemedicine platform integration for direct doctor access to adherence records

## Conclusion

In this project, an IoT-Based Smart Medicine Box has been successfully designed and developed to provide real-time pill consumption confirmation and remote caregiver monitoring for patients requiring strict medication adherence.
The system uses an ESP32 microcontroller as its central hub, coordinating FSR/load cell sensors (via HX711 modules), a 4×4 keypad, LCD display, buzzer, and LED indicators — all working together to deliver a multi-modal, confirmation-based medication management experience.
One of the most significant achievements of this project is the implementation of a weight-based confirmation mechanism that detects actual pill removal without the use of cameras, making the system both reliable and privacy-friendly. Cloud integration via Wi-Fi ensures that caregivers and doctors can monitor adherence status remotely, enabling timely intervention when doses are missed.
The design follows a four-week development timeline covering goal setting, breadboard prototyping, software development and debugging, and final 3D-printed enclosure assembly with soldered PCB — demonstrating a thorough and structured engineering approach.
With further enhancements — such as integration with telemedicine platforms, voice-command interfaces for severely mobility-impaired patients, or biometric swallowing confirmation using throat-worn sensors — this system has the potential to evolve into a comprehensive smart healthcare solution that can meaningfully improve quality of life and patient outcomes at scale.

## Project Development Photos

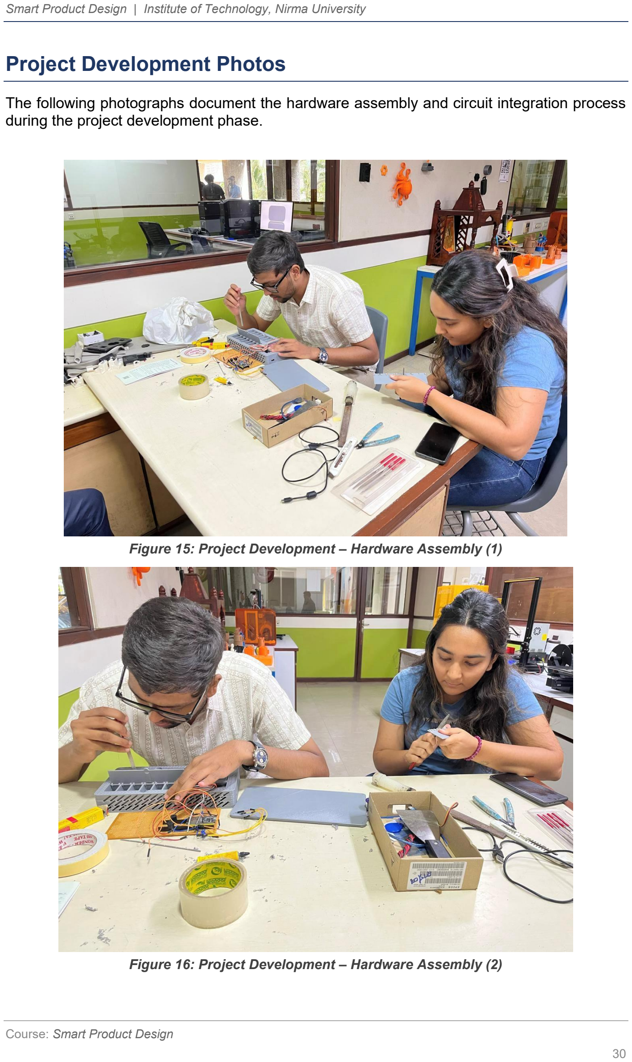
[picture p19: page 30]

The following photographs document the hardware assembly and circuit integration process during the project development phase.

Figure 15: Project Development – Hardware Assembly (1)

Figure 16: Project Development – Hardware Assembly (2)

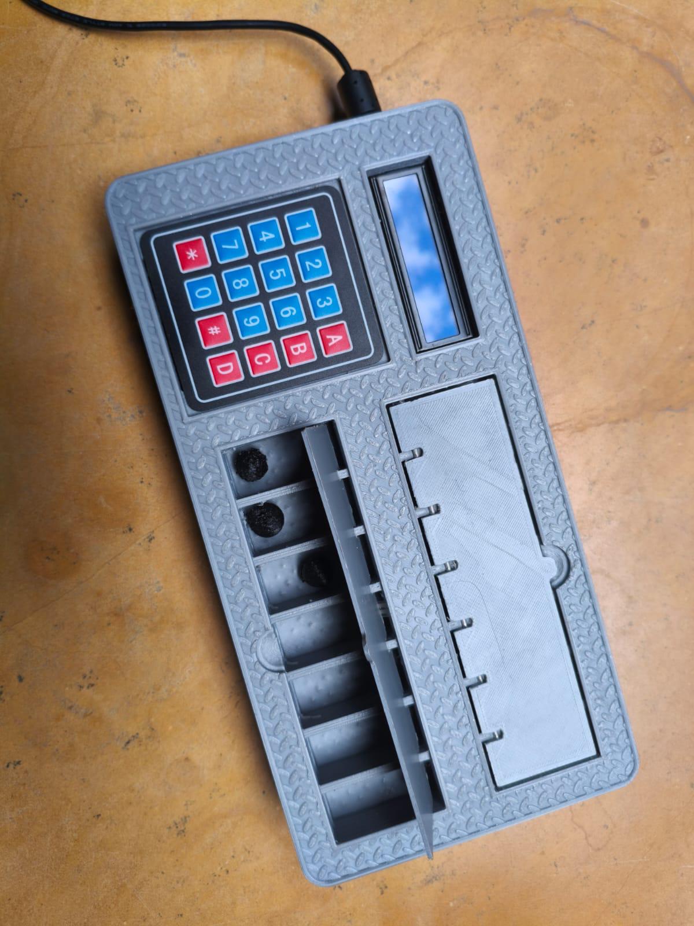
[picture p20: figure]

Figure 17: Project Development – Hardware Assembly (3)

## User Manual — Keypad Operation Guide

This section describes how to operate the Smart Medicine Box using the 4×4 membrane keypad, LCD display, and FSR sensor.

Keypad Layout and Key Functions

Key color coding: 0–9 = number input | # = confirm/enter | * = cancel/back | D = change
password | A = medicine settings | B = backspace/navigate

Table 9: Keypad Function Reference

Screen | Key | Action
Clock screen | # | Go to password entry / lock the box
Clock screen | A | Open medicine time settings (asks password first)
Password screen | 0–9 | Enter password digits
Password screen | # | Confirm password → unlock box
Password screen | B | Backspace — delete last digit entered
Password screen | D | Start change password flow
Password screen | * | Cancel → go back to clock screen
Alarm ringing | * | Manually dismiss alarm (treated as medicine taken)
Medicine settings | A / B | A = previous day, B = next day (navigate through 7 days)
Medicine settings | # | Edit selected day's medicine times
Edit day screen | 1 | Edit morning (AM) alarm time
Edit day screen | 2 | Edit evening (PM) alarm time
Set hour / minute | 0–9 + # | Type value then press # to confirm. B = backspace

Step-by-Step Operating Procedures

How to Unlock the Box
- On clock screen — press # to go to password entry
- Type your password using 0–9 keys (default password: 1234)
- Press # to confirm — "Access Granted!" appears on LCD
- Press * anytime to cancel and return to clock screen

How to Change the Password
- Press # on clock screen to go to password entry
- Press D — "Change Password" screen appears
- Type your OLD password and press #
- Type your NEW password and press #
- Type the new password again to confirm and press #
- LCD shows "Password Changed Successfully!"

How to Edit Medicine Alarm Times
- On clock screen — press A to open medicine settings
- Enter your password and press #
- Use A (previous day) and B (next day) to navigate to desired day
- Press # to edit the selected day
- Press 1 for morning time or 2 for evening time
- Type hour (0–23) and press # to confirm
- Type minutes (0–59) and press # — "Saved!" appears on LCD
- Press * to exit back to the clock screen

LCD Display Messages Reference

Table 10: LCD Display Messages Reference

LCD Shows | Meaning
MON 10:30:45 M:08:00 E:21:00 | Normal clock — current day/time and today's medicine times
Access Granted! | Password correct — box unlocked successfully
Access Denied! Tries left: 2 | Wrong password entered — shows remaining attempts
SYSTEM LOCKED! Wait: 8 sec | 3 wrong attempts — system locked for 10 seconds
MORNING MEDICINE / TAKE YOUR MED! | Medicine alarm ringing — take medicine now
Medicine Taken! at 08:03 | FSR sensor confirmed medicine removed from box
ALERT SENT! Family notified! | 10 minutes passed without taking medicine — family alerted via Telegram
Time Synced! MON 10:30 | NTP internet time synchronisation successful on boot
WiFi Failed! Offline Mode | No WiFi connection — device runs locally without Telegram or Blynk

FSR Sensor Values Guide

Table 11: FSR Sensor Values Guide

FSR Value | Meaning | System Action
0 | No weight — medicine NOT in box | Buzzer rings during alarm
1 – 2499 | Very light touch only | Buzzer continues ringing
2500 and above | Medicine placed in box — weight detected | Alarm stops — medicine taken recorded

Quick Start Summary: Power on the device → WiFi connects automatically → time syncs from

internet → place medicines in correct day compartments → device alarms at set times every

day. Default password is 1234. Change it immediately using the D key. Default alarm times

are 08:00 AM and 21:00 PM for all seven days.

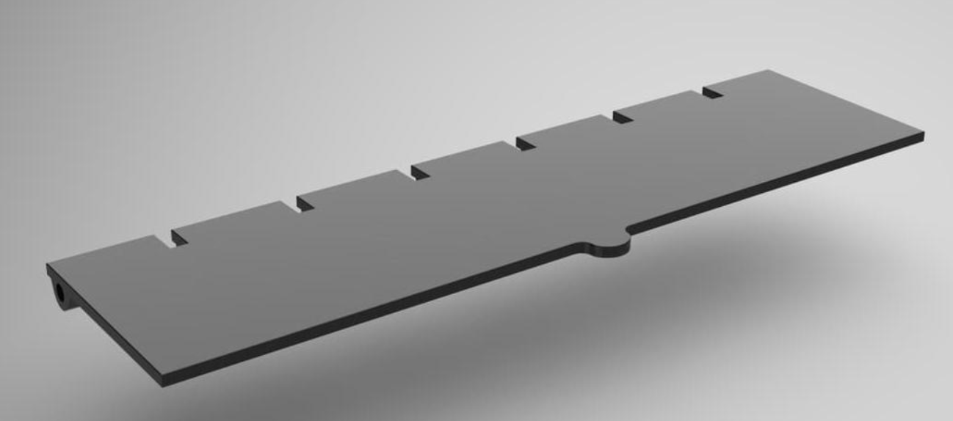
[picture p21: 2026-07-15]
images/Solidworks/Cap.png

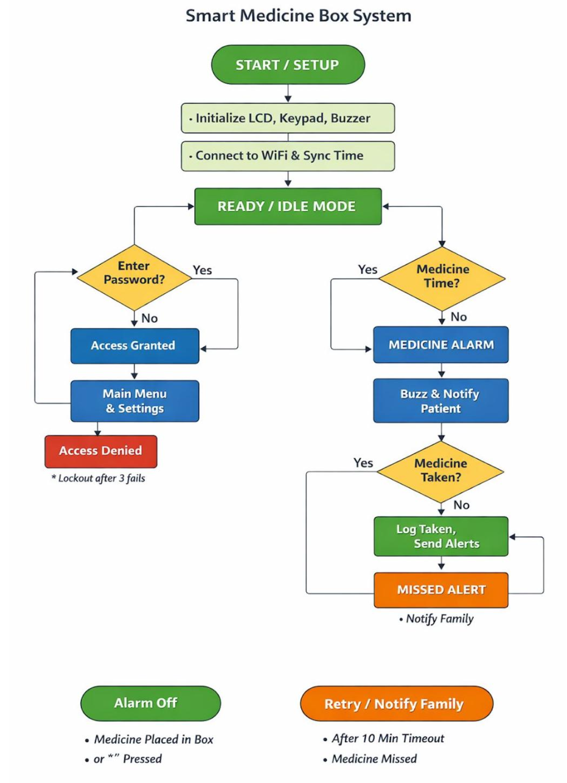
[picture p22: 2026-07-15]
images/Flow Chart/Flow chart.png

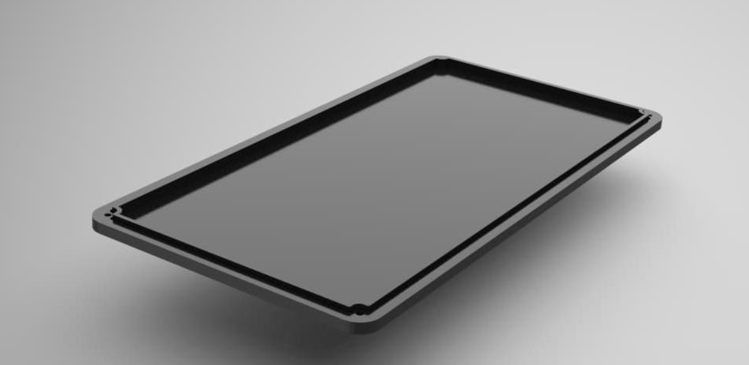
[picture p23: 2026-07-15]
images/Solidworks/Cover.png

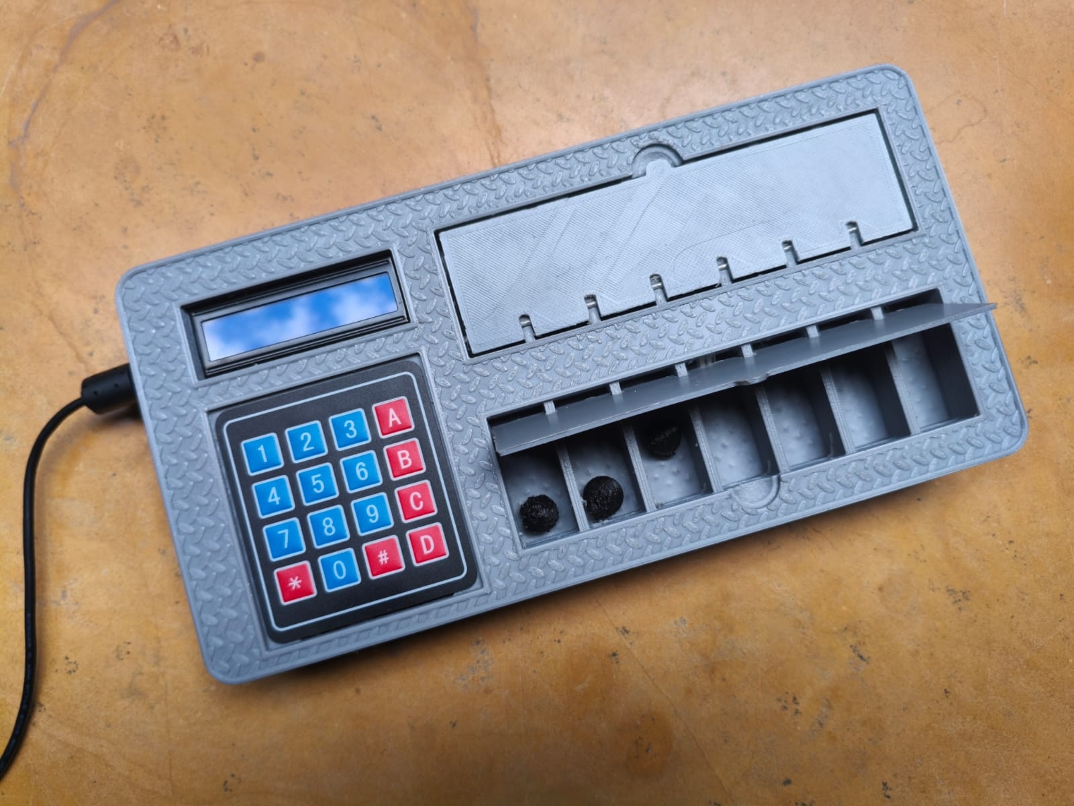
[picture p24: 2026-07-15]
images/Real images/Final Product.jpeg

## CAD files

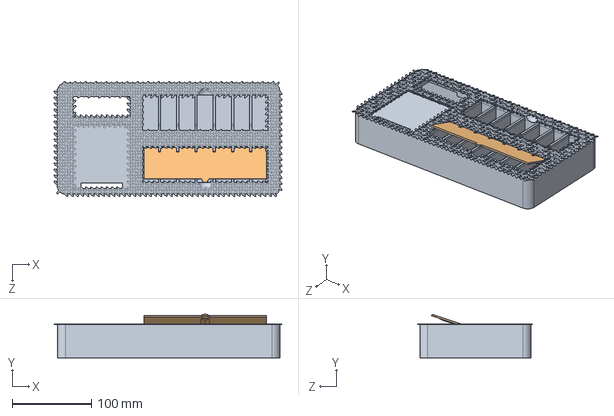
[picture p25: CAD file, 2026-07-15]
3d-Models/Assem1.SLDASM
286.9 x 54.9 x 144.7 mm
Base
Cap

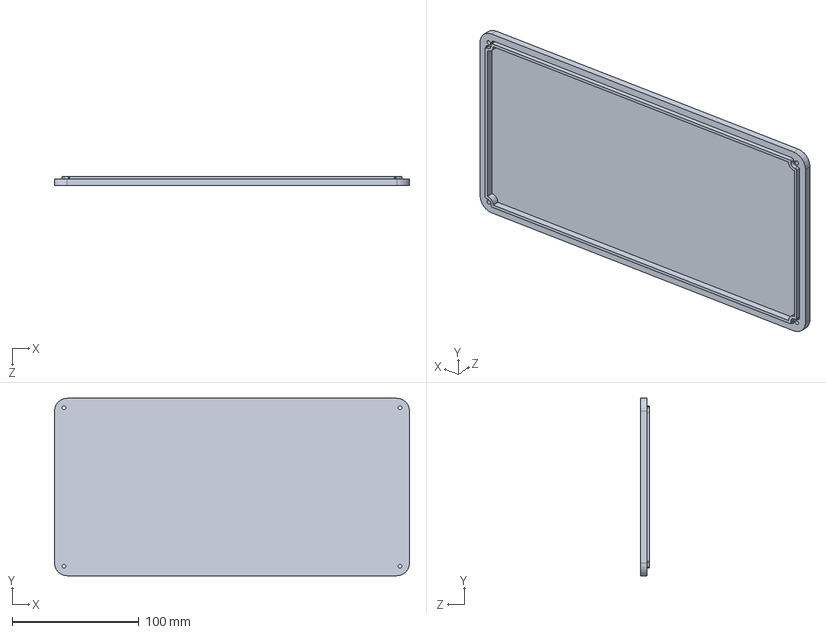
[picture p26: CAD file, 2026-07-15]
3d-Models/Cover.SLDPRT
280.0 x 140.0 x 7.00 mm

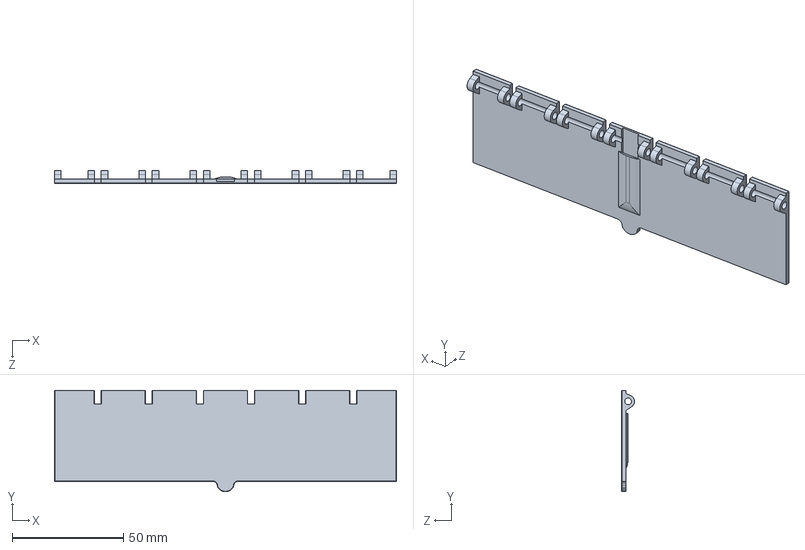
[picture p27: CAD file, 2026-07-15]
3d-Models/Cap.SLDPRT
154.0 x 45.7 x 5.92 mm

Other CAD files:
3d-Models/Cap.STL
3d-Models/Cover.STL

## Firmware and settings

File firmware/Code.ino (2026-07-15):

// ─── Fill these before uploading ──────────────────────────────────────────────
#define BLYNK_TEMPLATE_ID   "<blynk_template_id>"
#define BLYNK_TEMPLATE_NAME "<blynk_template_name>"
#define BLYNK_AUTH_TOKEN    "<blynk_auth_token>"
#define BLYNK_PRINT Serial

const char* WIFI_SSID     = "<wifi_name>";
const char* WIFI_PASSWORD = "<wifi_password>";

// ─── Telegram Config ──────────────────────────────────────────────────────────
const char* BOT_TOKEN      = "<bot_token_from_godfather>";
const char* PATIENT_CHATID = "<patient_chat_id";
const char* FAMILY_CHATID  = "<family_chat_id";
// ─────────────────────────────────────────────────────────────────────────────

#include <WiFi.h>
#include <HTTPClient.h>
#include <WiFiClientSecure.h>
#include <BlynkSimpleEsp32.h>
#include <Wire.h>
#include <LiquidCrystal_I2C.h>
#include <Keypad.h>
#include <time.h>

LiquidCrystal_I2C lcd(0x27, 16, 2);
const int BUZZER_PIN = 25;
const int FSR_PIN    = 34;

const byte ROWS = 4, COLS = 4;
char keys[ROWS][COLS] = {
  {'1','2','3','A'}, {'4','5','6','B'},
  {'7','8','9','C'}, {'*','0','#','D'}
};
byte rowPins[ROWS] = {13, 12, 14, 27};
byte colPins[COLS] = {26, 33, 32, 19};
Keypad keypad = Keypad(makeKeymap(keys), rowPins, colPins, ROWS, COLS);
BlynkTimer timer;

// ─── Password ─────────────────────────────────────────────────────────────────
String PASSWORD        = "1234";
String enteredPassword = "";
String newPassword     = "";
int    failedAttempts  = 0;
const  int MAX_ATTEMPTS = 3;
bool   isLocked        = false;
unsigned long lockStartTime = 0;
const unsigned long LOCK_DURATION = 10000;

// ─── Clock ────────────────────────────────────────────────────────────────────
int   clockHour=0, clockMin=0, clockSec=0, clockDay=0;
int   clockDate=1, clockMonth=3, clockYear=2026;
unsigned long lastMillis = 0;
bool  clockSet = false;
String dayNames[]   = {"SUN","MON","TUE","WED","THU","FRI","SAT"};
String monthNames[] = {"Jan","Feb","Mar","Apr","May","Jun",
                       "Jul","Aug","Sep","Oct","Nov","Dec"};

// ─── Medicine Times ───────────────────────────────────────────────────────────
int medTimes[7][4] = {
  {8,0,21,0},{8,0,21,0},{8,0,21,0},{8,0,21,0},
  {8,0,21,0},{8,0,21,0},{8,0,21,0}
};

// ─── Medicine Log ─────────────────────────────────────────────────────────────
struct MedLog { String date, type, status, time; };
MedLog medHistory[30];
int    medHistoryCount = 0;

// ─── Alarm State ──────────────────────────────────────────────────────────────
const unsigned long MED_BUZZ_DURATION = 10UL * 60UL * 1000UL;
bool  morningDone=false, eveningDone=false;
bool  alarmRinging=false;
String alarmType="";
unsigned long alarmStartTime=0, lastBuzzToggle=0;
bool  buzzState=false;
bool  medicineTaken=false, familyAlertSent=false, patientAlertSent=false;

String morningTakenTime="--:--", eveningTakenTime="--:--";
String morningStatus="Pending",  eveningStatus="Pending";

bool wifiConnected = false;

// ─── NTP ──────────────────────────────────────────────────────────────────────
unsigned long lastNTPSync = 0;
const unsigned long NTP_SYNC_INTERVAL = 3600000;

// ─── Modes ────────────────────────────────────────────────────────────────────
enum Mode {
  MODE_CLOCK, MODE_NORMAL,
  MODE_CHANGE_VERIFY, MODE_CHANGE_NEW, MODE_CHANGE_CONFIRM,
  MODE_MED_VERIFY, MODE_MED_SHOW, MODE_MED_SELECT_DAY,
  MODE_MED_SELECT_TYPE, MODE_MED_SET_HOUR, MODE_MED_SET_MIN
};
Mode currentMode = MODE_CLOCK;

int    medEditDay=0, medEditType=0;
String medInput="";
int    medVerifyFails=0, medShowDay=0;

// ─── Forward Declarations ─────────────────────────────────────────────────────
void showMessage(String l1, String l2, int ms = 0);
String twoDigitStr(int n);
String getMasked(String s);
void redrawLine(String prefix, String content);
void resetNormal();
void showTriesOnRow0();
void beepKey(); void beepBackspace(); void beepLimit();
void beepNoInput(); void beepSuccess(); void beepError();
void beepWarning(); void beepLocked(); void beepChanged();
void displayClock();
void showMedTimesForDay(int day);
void updateBlynkDashboard();
void addMedLog(String type, String status, String t);
void sendMonthlyLog();
void sendTelegram(String chatId, String message);
void telegramPatient(String msg);
void telegramFamily(String msg);
void telegramBoth(String msg);
void syncNTP();
void scanAndConnect();

// ─── WiFi Connect ─────────────────────────────────────────────────────────────
void scanAndConnect() {
  Serial.println("\n=== Scanning WiFi Networks ===");
  showMessage(" Scanning WiFi..","  Please wait...",0);
  WiFi.mode(WIFI_STA);
  WiFi.disconnect(true);
  delay(1000);

  int n = WiFi.scanNetworks();
  Serial.println("Found "+String(n)+" networks:");
  bool found = false;
  for(int i=0; i<n; i++){
    String ssid = WiFi.SSID(i);
    int rssi    = WiFi.RSSI(i);
    int channel = WiFi.channel(i);
    Serial.print(String(i+1)+") "+ssid);
    Serial.print("  "+String(rssi)+"dBm");
    Serial.print("  ch"+String(channel));
    if(channel > 14) Serial.print("  [5GHz!]");
    Serial.println();
    if(ssid == String(WIFI_SSID)){
      found = true;
      Serial.println(">>> FOUND! ch:"+String(channel)+" sig:"+String(rssi));
      if(channel > 14) showMessage("Hotspot is 5GHz!","Need 2.4GHz!    ",3000);
    }
  }
  if(!found){
    Serial.println("!!! '"+String(WIFI_SSID)+"' NOT FOUND!");
    showMessage("Hotspot NotFound","Check name/ON?  ",3000);
  }

  Serial.println("Connecting to: "+String(WIFI_SSID));
  showMessage(" Connecting...  ",String(WIFI_SSID).substring(0,16),0);
  WiFi.begin(WIFI_SSID, WIFI_PASSWORD);
  int tries=0;
  while(WiFi.status()!=WL_CONNECTED && tries<40){
    delay(500); tries++; Serial.print(".");
  }

  if(WiFi.status()==WL_CONNECTED){
    wifiConnected=true;
    Serial.println("\nWiFi Connected! IP: "+WiFi.localIP().toString());
    showMessage(" WiFi Connected!",WiFi.localIP().toString(),2000);
  } else {
    wifiConnected=false;
    Serial.println("\nWiFi FAILED!");
    switch(WiFi.status()){
      case WL_NO_SSID_AVAIL:  Serial.println("-> Not found!");    break;
      case WL_CONNECT_FAILED: Serial.println("-> Wrong password!"); break;
      default: Serial.println("-> Error: "+String(WiFi.status())); break;
    }
    showMessage(" WiFi Failed!   "," Offline Mode   ",2000);
  }
}

// ─── NTP Sync ─────────────────────────────────────────────────────────────────
void syncNTP() {
  if(!wifiConnected) return;
  struct tm timeinfo;
  if(!getLocalTime(&timeinfo)){Serial.println("NTP failed");return;}
  int prevDay=clockDay;
  clockHour=timeinfo.tm_hour; clockMin=timeinfo.tm_min; clockSec=timeinfo.tm_sec;
  clockDay=timeinfo.tm_wday; clockDate=timeinfo.tm_mday;
  clockMonth=timeinfo.tm_mon+1; clockYear=timeinfo.tm_year+1900;
  lastMillis=millis(); clockSet=true; lastNTPSync=millis();
  if(prevDay!=clockDay){
    morningDone=false; eveningDone=false;
    medicineTaken=false; familyAlertSent=false; patientAlertSent=false;
    morningTakenTime="--:--"; eveningTakenTime="--:--";
    morningStatus="Pending"; eveningStatus="Pending";
  }
  Serial.println("NTP: "+String(dayNames[clockDay])+" "+
    twoDigitStr(clockHour)+":"+twoDigitStr(clockMin)+":"+twoDigitStr(clockSec));
}

// ─── Telegram ─────────────────────────────────────────────────────────────────
void sendTelegram(String chatId, String message) {
  if (!wifiConnected) { Serial.println("Telegram skipped"); return; }

  Serial.println("Sending to: " + chatId);

  // URL encode message
  String encoded = "";
  for (int i = 0; i < message.length(); i++) {
    char c = message[i];
    if (c == ' ') encoded += '+';
    else if (c == '\n') encoded += "%0A";
    else if (c == ':') encoded += "%3A";
    else if (c == '!') encoded += "%21";
    else if (c == '?') encoded += "%3F";
    else if (c == '#') encoded += "%23";
    else if (c == '&') encoded += "%26";
    else encoded += c;
  }

  WiFiClientSecure client;
  client.setInsecure();
  client.setTimeout(15);

  if (!client.connect("api.telegram.org", 443)) {
    Serial.println("Connection to Telegram FAILED!");
    return;
  }

  String request = "GET /bot" + String(BOT_TOKEN) +
                   "/sendMessage?chat_id=" + chatId +
                   "&text=" + encoded +
                   " HTTP/1.1\r\n" +
                   "Host: api.telegram.org\r\n" +
                   "Connection: close\r\n\r\n";

  client.print(request);

  unsigned long timeout = millis();
  while (client.available() == 0) {
    if (millis() - timeout > 10000) {
      Serial.println("Telegram timeout!");
      client.stop();
      return;
    }
  }

  String response = "";
  while (client.available()) {
    response += (char)client.read();
  }
  client.stop();

  if (response.indexOf("\"ok\":true") >= 0) {
    Serial.println("Telegram OK! -> " + chatId);
  } else {
    Serial.println("Telegram response: " + response.substring(0, 150));
  }
}

void telegramPatient(String msg){ sendTelegram(String(PATIENT_CHATID), msg); }
void telegramFamily(String msg) { sendTelegram(String(FAMILY_CHATID),  msg); }
void telegramBoth(String msg)   { telegramPatient(msg); delay(1000); telegramFamily(msg); }

// ─── Medicine Log ─────────────────────────────────────────────────────────────
void addMedLog(String type, String status, String takenTime) {
  if(medHistoryCount>=30){for(int i=0;i<29;i++)medHistory[i]=medHistory[i+1];medHistoryCount=29;}
  MedLog entry;
  entry.date=String(clockDate)+" "+monthNames[clockMonth-1];
  entry.type=type; entry.status=status; entry.time=takenTime;
  medHistory[medHistoryCount]=entry; medHistoryCount++;
}

void sendMonthlyLog() {
  if(!wifiConnected) return;
  String log="";
  for(int i=medHistoryCount-1;i>=0;i--){
    String icon=(medHistory[i].status=="Taken")?"✅":"❌";
    log+=icon+" "+medHistory[i].date+" "+medHistory[i].type+" "+medHistory[i].time+"\n";
  }
  if(log=="") log="No records yet";
  Blynk.virtualWrite(V7, log);
}

// ─── Blynk ────────────────────────────────────────────────────────────────────
void updateBlynkDashboard() {
  if(!wifiConnected) return;
  Blynk.virtualWrite(V3, morningTakenTime);
  Blynk.virtualWrite(V4, eveningTakenTime);
  String morStr="MOR "+twoDigitStr(medTimes[clockDay][0])+":"+twoDigitStr(medTimes[clockDay][1])+" > "+morningStatus;
  if(morningStatus=="Taken") morStr+=" at "+morningTakenTime;
  Blynk.virtualWrite(V5, morStr);
  String eveStr="EVE "+twoDigitStr(medTimes[clockDay][2])+":"+twoDigitStr(medTimes[clockDay][3])+" > "+eveningStatus;
  if(eveningStatus=="Taken") eveStr+=" at "+eveningTakenTime;
  Blynk.virtualWrite(V6, eveStr);
  Blynk.virtualWrite(V8, analogRead(FSR_PIN));
  sendMonthlyLog();
}
void sendBlynkFSR(){if(!wifiConnected)return;Blynk.virtualWrite(V8,analogRead(FSR_PIN));}
void notifyPatient(String type){
  if(!wifiConnected||patientAlertSent)return;
  patientAlertSent=true;
  Blynk.logEvent("medicine_alarm","Time to take "+type+" medicine!");
}
void notifyMedicineTaken(String type,String takenTime){
  if(!wifiConnected)return;
  Blynk.logEvent("medicine_taken",type+" taken at "+takenTime);
  Blynk.virtualWrite(V2,1);delay(100);Blynk.virtualWrite(V2,0);
}
void notifyFamily(String type){
  if(!wifiConnected||familyAlertSent)return;
  familyAlertSent=true;
  Blynk.logEvent("family_alert","MISSED! "+type+" not taken!");
}

// ─── Buzzer ───────────────────────────────────────────────────────────────────
void playTone(int freq,int ms){ledcWriteTone(BUZZER_PIN,freq);ledcWrite(BUZZER_PIN,255);delay(ms);ledcWrite(BUZZER_PIN,0);delay(30);}
void beepKey()      {ledcWriteTone(BUZZER_PIN,2700);ledcWrite(BUZZER_PIN,255);delay(60);ledcWrite(BUZZER_PIN,0);delay(20);}
void beepBackspace(){playTone(1800,80);}
void beepLimit()    {playTone(500,300);}
void beepNoInput()  {playTone(800,200);}
void beepSuccess(){
  ledcWriteTone(BUZZER_PIN,1500);ledcWrite(BUZZER_PIN,255);delay(150);ledcWrite(BUZZER_PIN,0);delay(30);
  ledcWriteTone(BUZZER_PIN,2000);ledcWrite(BUZZER_PIN,255);delay(150);ledcWrite(BUZZER_PIN,0);delay(30);
  ledcWriteTone(BUZZER_PIN,2500);ledcWrite(BUZZER_PIN,255);delay(150);ledcWrite(BUZZER_PIN,0);delay(30);
  ledcWriteTone(BUZZER_PIN,3000);ledcWrite(BUZZER_PIN,255);delay(400);ledcWrite(BUZZER_PIN,0);
}
void beepError(){
  ledcWriteTone(BUZZER_PIN,800);ledcWrite(BUZZER_PIN,255);delay(250);ledcWrite(BUZZER_PIN,0);delay(50);
  ledcWriteTone(BUZZER_PIN,500);ledcWrite(BUZZER_PIN,255);delay(250);ledcWrite(BUZZER_PIN,0);delay(50);
  ledcWriteTone(BUZZER_PIN,300);ledcWrite(BUZZER_PIN,255);delay(500);ledcWrite(BUZZER_PIN,0);
}
void beepWarning(){for(int i=0;i<3;i++){ledcWriteTone(BUZZER_PIN,1500);ledcWrite(BUZZER_PIN,255);delay(120);ledcWrite(BUZZER_PIN,0);delay(80);}}
void beepLocked(){for(int i=0;i<5;i++){ledcWriteTone(BUZZER_PIN,2000);ledcWrite(BUZZER_PIN,255);delay(200);ledcWriteTone(BUZZER_PIN,500);ledcWrite(BUZZER_PIN,255);delay(200);}ledcWrite(BUZZER_PIN,0);}
void beepChanged(){
  ledcWriteTone(BUZZER_PIN,2000);ledcWrite(BUZZER_PIN,255);delay(100);ledcWrite(BUZZER_PIN,0);delay(50);
  ledcWriteTone(BUZZER_PIN,2500);ledcWrite(BUZZER_PIN,255);delay(100);ledcWrite(BUZZER_PIN,0);delay(50);
  ledcWriteTone(BUZZER_PIN,3000);ledcWrite(BUZZER_PIN,255);delay(300);ledcWrite(BUZZER_PIN,0);
}

// ─── LCD Helpers ──────────────────────────────────────────────────────────────
void showMessage(String l1,String l2,int ms){lcd.clear();lcd.setCursor(0,0);lcd.print(l1);lcd.setCursor(0,1);lcd.print(l2);if(ms>0)delay(ms);}
String twoDigitStr(int n){return n<10?"0"+String(n):String(n);}
String getMasked(String s){String m="";for(int i=0;i<(int)s.length();i++)m+='*';return m;}
void redrawLine(String prefix,String content){lcd.setCursor(0,1);lcd.print(prefix);lcd.print("              ");lcd.setCursor(prefix.length(),1);lcd.print(content);}
void resetNormal(){currentMode=MODE_NORMAL;enteredPassword="";newPassword="";lcd.clear();lcd.setCursor(0,0);lcd.print("Enter Password: ");lcd.setCursor(0,1);lcd.print(">               ");lcd.setCursor(2,1);}
void showTriesOnRow0(){lcd.setCursor(0,0);lcd.print("Tries left: ");lcd.print(MAX_ATTEMPTS-failedAttempts);lcd.print("    ");}
void showMedTimesForDay(int day){
  lcd.clear();lcd.setCursor(0,0);
  lcd.print(dayNames[day]);lcd.print(" M:");
  lcd.print(twoDigitStr(medTimes[day][0]));lcd.print(":");lcd.print(twoDigitStr(medTimes[day][1]));
  lcd.print(" E:");lcd.print(twoDigitStr(medTimes[day][2]));lcd.print(":");lcd.print(twoDigitStr(medTimes[day][3]));
  lcd.setCursor(0,1);lcd.print("A/B=nav #=edit *=exit");
}

// ─── Clock ────────────────────────────────────────────────────────────────────
void updateClock(){
  if(!clockSet) return;
  if(wifiConnected&&millis()-lastNTPSync>NTP_SYNC_INTERVAL){syncNTP();return;}
  unsigned long now=millis(),diff=now-lastMillis;
  if(diff>=1000){
    int secs=diff/1000;lastMillis+=secs*1000;clockSec+=secs;
    if(clockSec>=60){clockSec-=60;clockMin++;}
    if(clockMin>=60){clockMin=0;clockHour++;}
    if(clockHour>=24){
      clockHour=0;clockDay=(clockDay+1)%7;clockDate++;
      if(clockDate>30){clockDate=1;clockMonth++;if(clockMonth>12){clockMonth=1;clockYear++;}}
      morningDone=false;eveningDone=false;
      medicineTaken=false;familyAlertSent=false;patientAlertSent=false;
      morningTakenTime="--:--";eveningTakenTime="--:--";
      morningStatus="Pending";eveningStatus="Pending";
      updateBlynkDashboard();
    }
  }
}

void checkMedicineAlarms(){
  if(!clockSet||alarmRinging) return;
  if(clockHour==medTimes[clockDay][0]&&clockMin==medTimes[clockDay][1]&&clockSec==0&&!morningDone){
    morningDone=true;alarmRinging=true;alarmStartTime=millis();lastBuzzToggle=millis();
    buzzState=false;alarmType="MORNING";medicineTaken=false;familyAlertSent=false;patientAlertSent=false;
    morningStatus="Alarm!";lcd.clear();
    telegramPatient("💊 MEDICINE REMINDER\n📅 "+String(clockDate)+" "+monthNames[clockMonth-1]+"\n⏰ "+twoDigitStr(clockHour)+":"+twoDigitStr(clockMin)+"\n🌅 Take your MORNING medicine!");
    notifyPatient("MORNING");updateBlynkDashboard();
  }
  if(clockHour==medTimes[clockDay][2]&&clockMin==medTimes[clockDay][3]&&clockSec==0&&!eveningDone){
    eveningDone=true;alarmRinging=true;alarmStartTime=millis();lastBuzzToggle=millis();
    buzzState=false;alarmType="EVENING";medicineTaken=false;familyAlertSent=false;patientAlertSent=false;
    eveningStatus="Alarm!";lcd.clear();
    telegramPatient("💊 MEDICINE REMINDER\n📅 "+String(clockDate)+" "+monthNames[clockMonth-1]+"\n⏰ "+twoDigitStr(clockHour)+":"+twoDigitStr(clockMin)+"\n🌙 Take your EVENING medicine!");
    notifyPatient("EVENING");updateBlynkDashboard();
  }
}

// ─── FSR Check (NEW LOGIC) ────────────────────────────────────────────────────
void checkFSR(){
  if(!alarmRinging) return;
  int fsrValue=analogRead(FSR_PIN);
  static unsigned long lastPrint=0;
  if(millis()-lastPrint>300){
    Serial.print("FSR: ");Serial.println(fsrValue);
    lastPrint=millis();
  }

  // ✅ NEW: FSR >= 2500 means medicine placed in box → stop alarm
  if(fsrValue >= 2500){
    String takenTime=twoDigitStr(clockHour)+":"+twoDigitStr(clockMin);
    alarmRinging=false;medicineTaken=true;
    ledcWrite(BUZZER_PIN,0);beepSuccess();
    if(alarmType=="MORNING"){morningTakenTime=takenTime;morningStatus="Taken";}
    else{eveningTakenTime=takenTime;eveningStatus="Taken";}
    addMedLog(alarmType,"Taken",takenTime);
    telegramBoth("✅ MEDICINE TAKEN!\n📅 "+String(clockDate)+" "+monthNames[clockMonth-1]+"\n💊 "+alarmType+" taken at "+takenTime+"\n👍 Great job!");
    notifyMedicineTaken(alarmType,takenTime);
    updateBlynkDashboard();
    lcd.clear();
    lcd.setCursor(0,0);lcd.print(" Medicine Taken!");
    lcd.setCursor(0,1);lcd.print("  at ");lcd.print(takenTime);lcd.print("  :) ");
    delay(2000);lcd.clear();
  }
}

void updateMedicineBuzz(){
  if(!alarmRinging) return;
  unsigned long now=millis();
  if(now-alarmStartTime>=MED_BUZZ_DURATION){
    alarmRinging=false;ledcWrite(BUZZER_PIN,0);
    if(!medicineTaken){
      if(alarmType=="MORNING"){morningStatus="Missed";morningTakenTime="--:--";}
      else{eveningStatus="Missed";eveningTakenTime="--:--";}
      addMedLog(alarmType,"Missed","--:--");
      telegramFamily("❌ MEDICINE MISSED!\n📅 "+String(clockDate)+" "+monthNames[clockMonth-1]+"\n💊 "+alarmType+" NOT taken!\n🙏 Please check on the patient!");
      telegramPatient("⚠️ MISSED MEDICINE!\n📅 "+String(clockDate)+" "+monthNames[clockMonth-1]+"\nYou missed your "+alarmType+" medicine!\nPlease take it now. 🙏");
      notifyFamily(alarmType);updateBlynkDashboard();
      lcd.clear();lcd.setCursor(0,0);lcd.print("  ALERT SENT!   ");lcd.setCursor(0,1);lcd.print("Family notified!");delay(3000);
    }
    lcd.clear();return;
  }
  // ✅ NEW: buzz when FSR = 0 (medicine not in box)
  int fsrNow = analogRead(FSR_PIN);
  if(fsrNow < 2500){
    if(now-lastBuzzToggle>=500){
      lastBuzzToggle=now;buzzState=!buzzState;
      if(buzzState){ledcWriteTone(BUZZER_PIN,2500);ledcWrite(BUZZER_PIN,255);}
      else{ledcWrite(BUZZER_PIN,0);}
    }
  } else {
    ledcWrite(BUZZER_PIN,0); // silent if medicine already placed
  }
}
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
void loop(){
  if(wifiConnected){Blynk.run();timer.run();}
  updateClock();
  checkMedicineAlarms();
  updateMedicineBuzz();
  checkFSR();

  if(isLocked&&!alarmRinging){
    unsigned long elapsed=millis()-lockStartTime;
    if(elapsed>=LOCK_DURATION){isLocked=false;failedAttempts=0;beepKey();currentMode=MODE_CLOCK;lcd.clear();}
    else{int s=(LOCK_DURATION-elapsed)/1000+1;lcd.setCursor(0,0);lcd.print(" SYSTEM  LOCKED ");lcd.setCursor(0,1);lcd.print("  Wait: ");lcd.print(s);lcd.print(" sec    ");delay(400);return;}
  }

  if(alarmRinging){
    static unsigned long lastDisplay=0;
    if(millis()-lastDisplay>300){showMedicineAlarm();lastDisplay=millis();}
    char key=keypad.getKey();
    if(key=='*'){
      String takenTime=twoDigitStr(clockHour)+":"+twoDigitStr(clockMin);
      alarmRinging=false;medicineTaken=true;ledcWrite(BUZZER_PIN,0);beepKey();
      if(alarmType=="MORNING"){morningTakenTime=takenTime;morningStatus="Taken";}
      else{eveningTakenTime=takenTime;eveningStatus="Taken";}
      addMedLog(alarmType,"Taken",takenTime);
      telegramBoth("✅ MEDICINE TAKEN!\n📅 "+String(clockDate)+" "+monthNames[clockMonth-1]+"\n💊 "+alarmType+" taken at "+takenTime+"\n👍 Great job!");
      notifyMedicineTaken(alarmType,takenTime);updateBlynkDashboard();
      showMessage("  Alarm Stopped "," Take Medicine! ",2000);lcd.clear();
    }
    return;
  }

  if(currentMode==MODE_CLOCK&&clockSet){
    static int lastSec=-1;
    if(clockSec!=lastSec){displayClock();lastSec=clockSec;}
  }

  if(!clockSet){
    lcd.setCursor(0,0);lcd.print(" Waiting for    ");
    lcd.setCursor(0,1);lcd.print(" WiFi + Time... ");
    return;
  }

  char key=keypad.getKey();
  if(!key) return;

  switch(currentMode){
    case MODE_CLOCK:
      if(key=='#'){beepKey();resetNormal();}
      else if(key=='A'){beepKey();medVerifyFails=0;enteredPassword="";currentMode=MODE_MED_VERIFY;lcd.clear();lcd.setCursor(0,0);lcd.print("Med Settings:   ");lcd.setCursor(0,1);lcd.print("Password: ");}
      break;
    case MODE_NORMAL:         handleNormalMode(key);    break;
    case MODE_CHANGE_VERIFY:  handleChangeVerify(key);  break;
    case MODE_CHANGE_NEW:     handleChangeNew(key);     break;
    case MODE_CHANGE_CONFIRM: handleChangeConfirm(key); break;
    case MODE_MED_VERIFY:     handleMedVerify(key);     break;
    case MODE_MED_SHOW:       handleMedShow(key);       break;
    case MODE_MED_SELECT_DAY: handleMedSelectType(key); break;
    case MODE_MED_SET_HOUR:   handleMedSetHour(key);    break;
    case MODE_MED_SET_MIN:    handleMedSetMin(key);     break;
  }
}
